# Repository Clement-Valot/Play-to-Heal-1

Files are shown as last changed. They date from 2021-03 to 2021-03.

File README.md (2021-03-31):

# Play-to-Heal

## Résumé

En France, d’après l’INSEE, 3,5 millions de personnes sont en situation de handicap physique. Cela ne concerne que 5% des Français et bien que tous différents, la majorité des handicaps ont un point commun : les exercices de rééducation musculaire.  

L’objectif de ces exercices est de recouvrer partiellement, ou totalement, ses capacités physiques ou encore de simplement les préserver. En faisant travailler ses muscles au travers de la répétition de mouvements particuliers, le patient se réhabitue petit à petit à se mouvoir. Cependant, cela comporte un aspect répétitif et ennuyeux, en particulier pour les enfants, mais c’est nécessaire au maintien ou à l’amélioration des fonctions motrices des patients.  

Ainsi, notre objectif avec Play To Heal est de rendre ces exercices plus ludiques pour les personnes ayant des difficultés motrices. Pour y parvenir nous avons utilisé la gamification, ou ludification, qui est l’utilisation des mécanismes du jeu dans des domaines n’ayant à priori aucun rapport afin de rendre l’expérience utilisateur plus ludique et agréable.  

Notre solution utilise la manette adaptative Xbox, sorti en fin d’année 2018, couplée à un périphérique externe développé par nos soins. Il suffit de placer les électrodes sur un ou plusieurs muscles et les contractions du joueur sont directement utilisées pour agir dans le jeu vidéo. Bien entendu, il est possible de jouer à tous les jeux disponibles sur Xbox, même s’il est conseillé d’en choisir un nécessitant peu de touches si le patient est amené à jouer seul. 

Pour conclure, nous vous invitons à parcourir tous les documents disponibles pour plus d’informations sur le projet si vous n’êtes pas encore convaincu ! 

Pour voir notre vidéo de présentation, c'est ici : https://www.youtube.com/watch?v=-XGQ_6M441o (version sous-titrée en anglais : https://www.youtube.com/watch?v=T63vXXvgbwU )

Pour voir notre vidéo de démo, c'est par là : https://www.youtube.com/watch?v=D4KDB941Q0I 

## Sommaire

#### 3D modeling

Vous trouverez dans ce dossier les modélisations des différentes pièces du boîtier Mono-muscle et Multi-muscle. Pour les deux versions du boîtier, 2 dossiers sont fournis: l'un contenant les pièces au format SolidWorks (.SLDASM) et l'autre au format .STL pour impression en 3D.

#### Codes and libraries

Les 2 sous dossiers (code multi muscles SIG et code multi muscles RAW) contiennent chacun le logo affiché sur l'écran OLED lors de l'allumage du boîtier, nommé "logo.h", et le code Arduino (C++) correspondant.

#### Documentation

Ce dossier est dédié pour toutes informations complémentaires au boîtier Play to Heal concernant: les différents composants électroniques, le filtrage numérique, l'analyse de coûts, etc... 
Tous sont accessibles au format PDF.

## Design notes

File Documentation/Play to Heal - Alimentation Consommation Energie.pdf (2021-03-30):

# Alimentation du dispositif et consommation d’énergie

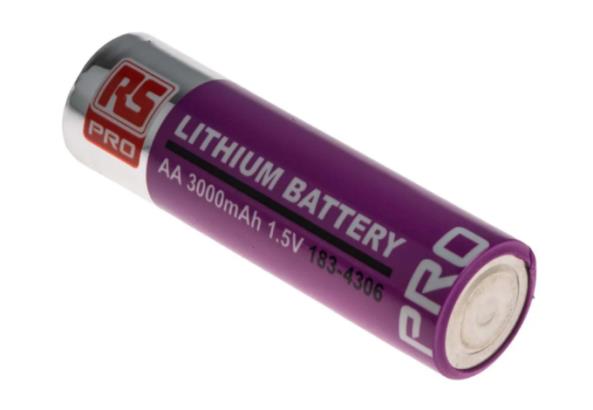
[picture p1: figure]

## Table des matières

## Etat de l’art

L’ESP 32, l’élément central de notre dispositif fonctionne avec une tension comprise entre 2.5 et 3.6 volts. Il faut donc trouver une source d’énergie qui puisse apporter une telle tension. Plusieurs solutions s’offrent à nous :

1. On pourrait brancher le montage directement à la manette Xbox adaptative mais celle-ci offre une tension de 5V qui est au-dessus du seuil maximum de notre microcontrôleur. Il faudrait donc réaliser un montage électrique pour réduire cette tension, ce qui n’est pas optimal.
2. Au contraire, des piles NiMH ou standards n’apportent pas assez de courant pour que l’ESP32 puisse fonctionner correctement. Les piles fournissent environ 1,2V (soit 2.4V avec 2 piles). Or la tension minimale de l’ESP 32 est d’environ 2.55V.
3. Utiliser un banc d’alimentation est également une mauvaise idée car ce type de batterie utilise en interne une batterie au lithium de 3.7V puis transforme la tension afin de délivrer 5V. Il faudra donc ramener de nouveau la tension à 3.6V à l’instar du procédé avec la manette. Les transformations successives sont énergivores et sont à éviter. Enfin ce type de batterie peut parfois s’éteindre car il peut arriver qu’elle pense qu’aucune charge n’est connectée tant l’ESP32 consomme peu de courant.
4. Les batteries LiFePO4 modernes fonctionnent également très bien, mais fournissent environ 70 % d’énergie en moins qu’une batterie au lithium de la même taille. Les batteries LiFePO4 sont bien adaptées à un fonctionnement à court terme, c’est-à-dire des semaines et des mois. Il est également important de noter qu’un chargeur 3V spécial adapté aux batteries LiFePO4 est nécessaire.

Après l’étude de toutes ces possibilités, il s’est avéré que la solution la plus optimale était d’utiliser des piles au lithium. En effet, ce type de batterie délivre une tension constante dans le temps jusqu’à sa fin de vie. Nous avons choisi celles délivrant 1.5V car en les mettant en parallèles nous doublons la tension, ce qui correspond bien aux contraintes de l’ESP32.

## Rôle dans le projet

L’utilisation de ces piles offre une alimentation simple et efficace à notre dispositif. Nous n’avons pas besoin de le brancher sur secteur, ce qui permet d’éviter de s’encombrer avec des fils supplémentaires pour utiliser l’appareil. De plus la longue durée de vie des piles au lithium assure une grande autonomie à notre projet. Nos deux piles de 1,5V vont nous fournir une tension optimale pour alimenter l’ESP32 et l’écran OLED. De plus, leur positionnement dans le boitier permettra à l’utilisateur de les changer facilement lorsqu‘elles cesseront de fonctionner.

## Consommation énergétique

Afin de se rendre compte de la fréquence à laquelle il faudra changer les piles, nous allons dans un premier temps étudier chaque composant demandeur d’énergie puis la source d’énergie et enfin nous associerons le tout.

Ce n’est pas précisé dans les figures qui vont suivre mais la consommation écrite représente toujours la consommation pour une heure de fonctionnement.

### Explication

Comme expliqué dans le choix de la source d’énergie, les piles au lithium sont très fiables et sont la source d’énergie la plus optimisée. En effet, elles maintiennent une tension de 3V assez constante puis à moins de 2,7 volts plus de 90 % de leur capacité est utilisée et enfin à 2,55V elles sont pratiquement vides, or pour fonctionner l’ESP32 à besoin d’au moins 2,55V.

Concernant l’autonomie du système, on peut voir que les piles ont une capacité de 2900mAh. A noter que le fait de les mettre en parallèle n’augmente que la tension et non le courant, ce qui explique pourquoi nous travaillons avec 2900mAh malgré le fait que nous utilisons deux piles.

Pour étudier combien de temps notre système peut fonctionner sans changer les piles, on additionne la consommation de tous les composants pour une heure :

- 40mA (ESP32)
- 9mA (Myoware)
- 40mA (OLED)
Ce qui nous donne 89mAh. Cependant l’écran OLED ne sert qu’à l’initialisation, soit maximum deux minutes sur l’heure de fonctionnement, ainsi il peut être négligé.

Nous ne consommons finalement que 49mAh. De ce fait, notre système pourrait fonctionne plus d’une cinquantaine d’heures (2900/49) avant de changer les piles.

### Consommation par composant

ESP32

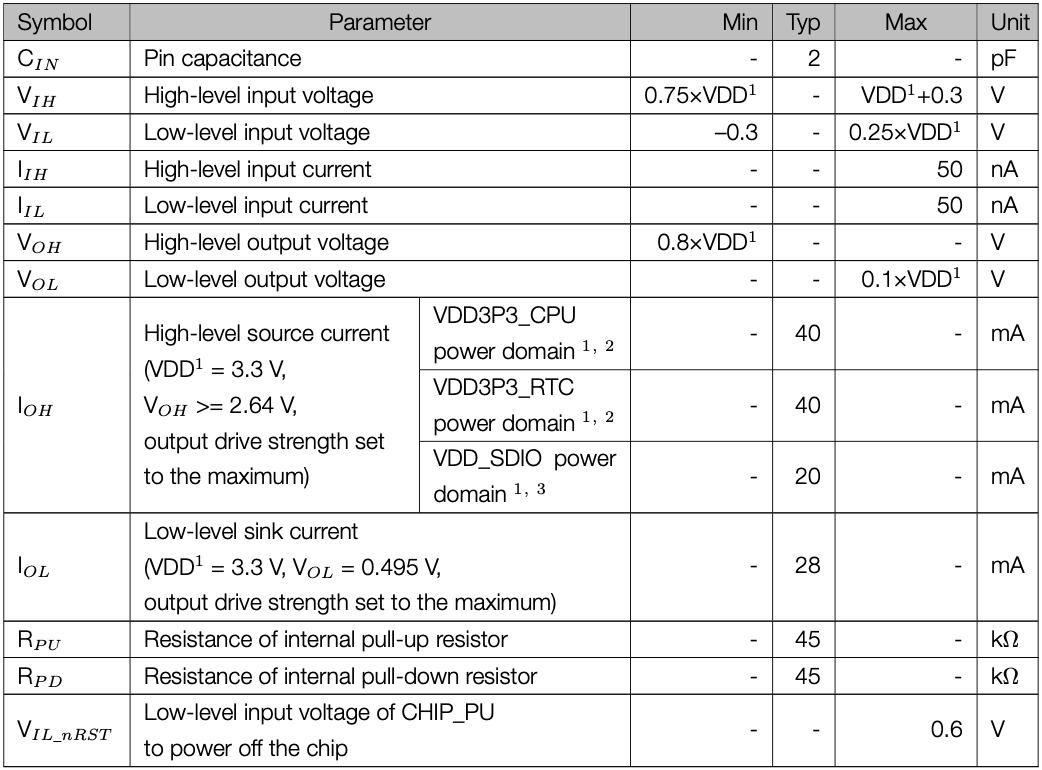
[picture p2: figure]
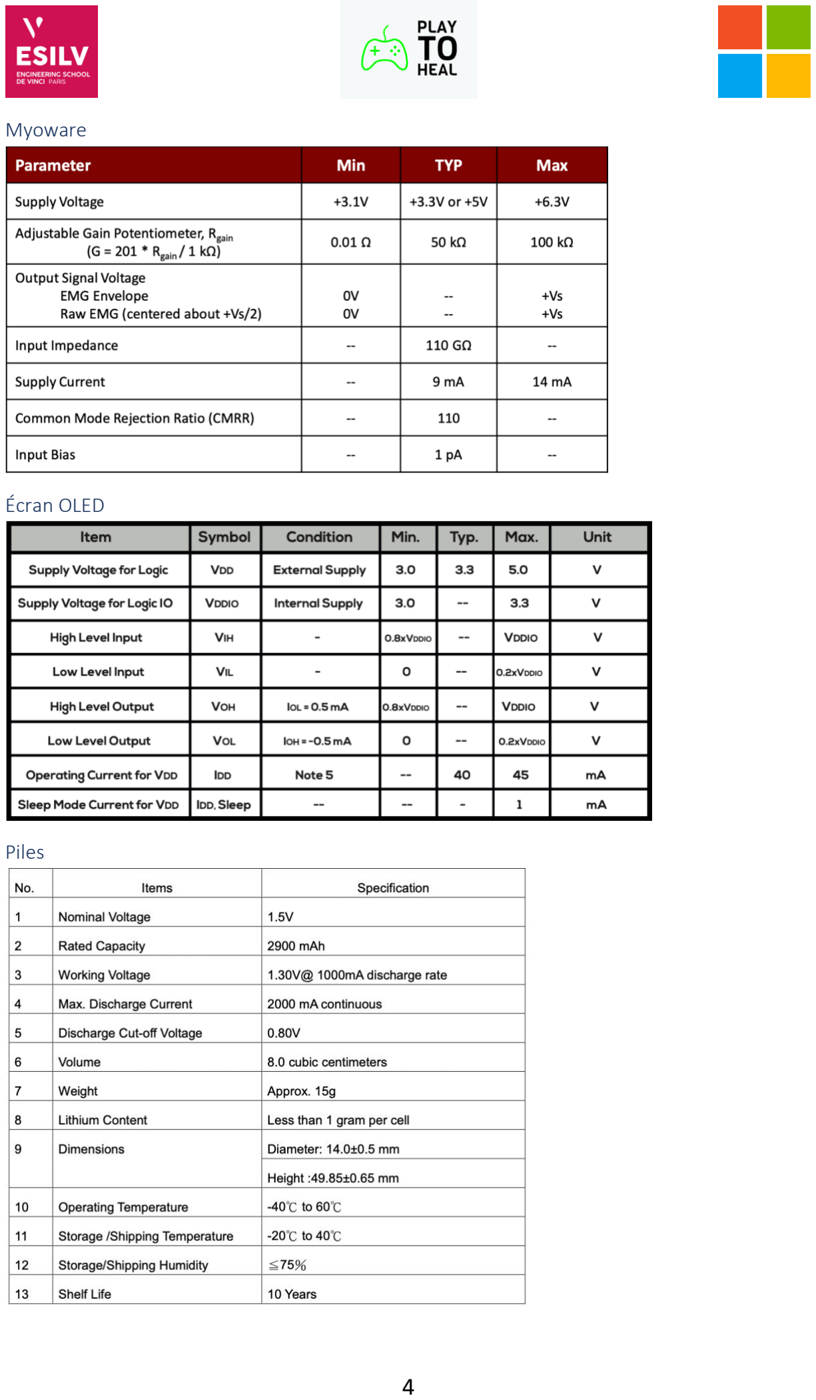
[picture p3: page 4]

Myoware

Écran OLED

Piles

## Bibliographie

https://fr.rs-online.com/web/p/piles-aa/1834306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 (https://fr.rs-online.com/web/p/piles-aa/1834306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)

ESP32 : https://www.espressif.com/sites/default/files/documentation/esp32_datasheet_en.pdf

Myoware : https://cdn.sparkfun.com/assets/a/3/a/f/a/AT-04-001.pdf

OLED: | https://cdn.shopify.com/s/files/1/1509/1638/files/1_3_Zoll_Display_Datenblatt_AZ-
Delivery_Vertriebs_GmbH_rev.pdf?v=1606164520 (https://cdn.shopify.com/s/files/1/1509/1638/files/1_3_Zoll_Display_Datenblatt_AZ-Delivery_Vertriebs_GmbH_rev.pdf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)

Piles : https://docs.rs-online.com/0394/0900766b81707a84.pdf

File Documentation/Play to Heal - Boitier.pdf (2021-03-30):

# Boitier

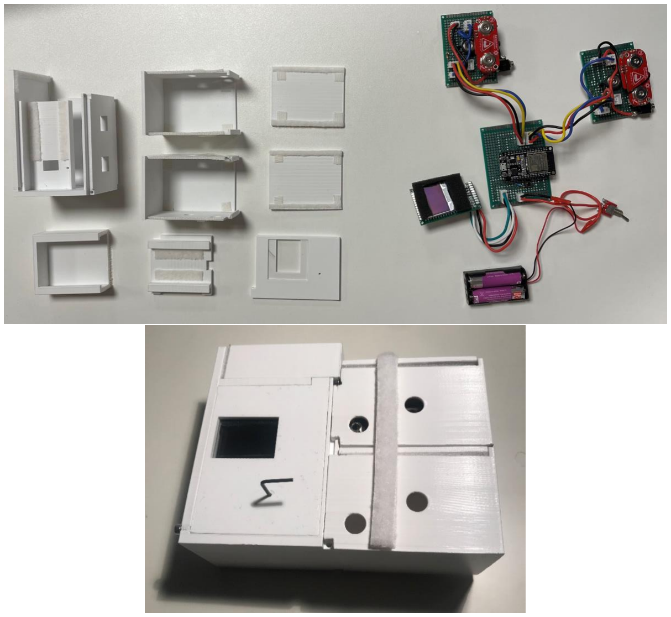
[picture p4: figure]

## Table des matières

1
2
1
2

## Introduction

Pour commencer, il faut savoir que nous avions pour objectif de rendre un produit industrialisable. De ce fait, rendre le projet sous forme de PCB connectés entre eux par des fils n’était pas suffisant. C’est ainsi que nous est venue l’idée d’un boitier permettant de délivrer notre projet sous une forme concrète.

En effet, le boitier s’est révélé comme étant la solution idéale pour rendre un projet fini à la fin de l’année. Il a les avantages d’être :

- esthétique car il cache les composants électroniques,
- sécurisé car les composants électroniques ont moins de chances de s’abimer
- pratique car il est facile à monter même pour quelqu’un qui ne s’y connaît pas,
- transportable car l’optimisation de l’espace pour les composants a été optimisé au maximum et que le boitier tient dans une main.
- professionnel car il représente l’aspect fini et abouti de ce projet.

Cette idée était d’autant plus réalisable que nous étions 9 dans l’équipe et avions donc plus de moyens humains pour dédier plusieurs personnes du groupe à sa conception, en l’occurrence deux. Les imprimantes du pôle mises à disposition au FabLab nous ont également été d’une grande aide.

Aujourd’hui, nous sommes très fiers du modèle multi muscles que nous avons produit parce qu’il représente réellement toute l’implication et l’effort mis dans ce projet par toute l’équipe. Dans ce document, nous allons expliquer la démarche que nous avons suivi de la réflexion à la construction en passant par la conception.

## Par où commencer ?

Notre toute première initiative de construction de boitier était de récupérer des planches de bois de 3mm au FabLab et de limer leurs côtés pour pouvoir les imbriquer entre elles.

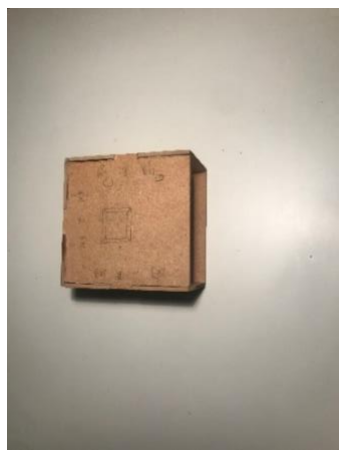
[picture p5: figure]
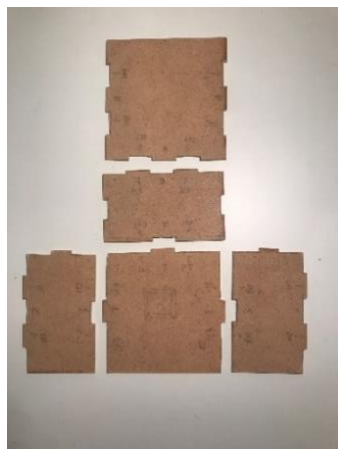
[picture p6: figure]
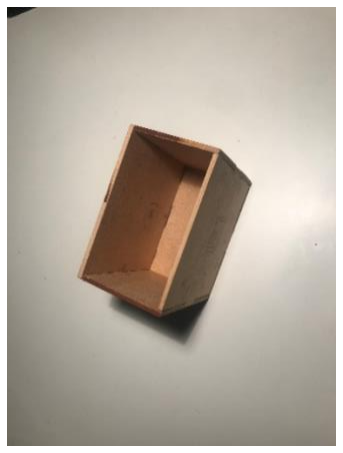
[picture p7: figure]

Le résultat n’est pas fameux mais le but était de nous faire prendre conscience que pour construire notre boitier, il fallait commencer par se poser les bonnes questions :

- Quelles vont être les dimensions du boitier ?
- Que devons-nous pouvoir mettre à l’intérieur ? Comment fixer les composants à l’intérieur du boitier pour éviter qu’ils soient volatiles et qu’ils s’abîment à la moindre secousse du boitier ?

- Quels composants doivent être accessibles par l’utilisateur et lesquels doivent être cachés ?
- Une boîte ne pouvant pas être modélisée avec une imprimante 3D de notre FabLab, combien de pièces différentes devons-nous concevoir ?
- Le boitier doit-il pouvoir être démontable facilement ?
- En quel matériau le construire (bois, imprimante 3D, plastique, métal) ?
- Comment placer l’OLED dans le boitier tout en le rendant visible depuis l’extérieur ?
- Comment fixer les différentes pièces entre elles ? Imbrication parfaite ? Vis ? Scratch ? Scotch ? Colle ?
- Comment rendre des éléments accessibles par l’extérieur sans ouvrir le boitier ? (pour l’interrupteur, l’embout du myoware pour y brancher les électrodes, la prise jack femelle, ainsi que le bouton connecté à l’ESP32)

Nous sommes rapidement arrivés à la conclusion qu’il fallait que l’on construise notre boitier à l’aide d’une imprimante 3D. Et pour cela, nous avions besoin d’un logiciel de modélisation 3D et nous avons donc récupéré des licences SolidWorks fournies par l’école.

A partir de là, le schéma était plus clair dans nos têtes :

1. Il fallait commencer par modéliser les pièces électroniques composant notre produit (myoware, esp32, jack femelle…) afin de voir en les rapprochant au maximum quels pourraient être les dimensions optimales du boitier.
2. Ensuite, il fallait esquisser un premier modèle de boitier permettant d’imbriquer chaque composants à l’intérieur en prenant soin de ne pas laisser trop de leste. De plus, il fallait bien séparer le nombre de pièces afin de rendre le montage le plus simple possible.
3. Enfin il fallait imprimer pour voir concrètement ce à quoi nous n’avions pas pensé et ce qu’il fallait changer.

## Modélisation des pièces électroniques

Il n’y a pas grand-chose à dire sur la modélisation de ces pièces si ce n’est qu’elles restaient assez précises et difficiles à modéliser. Mais leur importance était grande car c’est elles qui nous ont permis de voir si le boitier imprimé allait bien faire rentrer les vrais composants. Malheureusement, ces pièces n’ont pas résolu tous nos maux notamment ceux liés à l’imbrication des pièces entre elles, les défauts de modélisation dus au support des imprimantes ou encore les trous/espaces nécessaires aux fils et câbles.

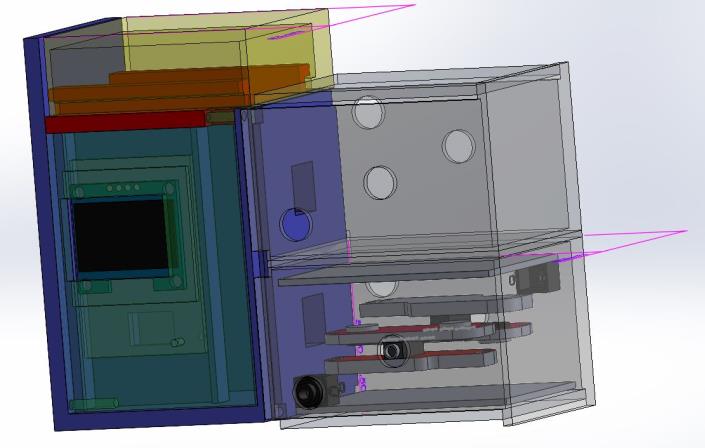
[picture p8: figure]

Evidemment, ces pièces-là n’ont pas été imprimées, elles ont seulement servi de repère pour modéliser le boitier sur SolidWorks.

## Modélisation des pièces du boitier

Il est impossible de construire une boite telle quelle avec une imprimante 3D. Pour ce faire, il faut créer différentes pièces que l’on fixe ensuite entre elles pour former la boîte. Dans notre cas nous avons imaginé notre boitier en 4 pièces :

1. La pièce principale qui va être le squelette de notre boitier et contenir la plupart des composants électroniques. Elle doit être faite de telle sorte qu’elle puisse laisse sortir le levier de l’interrupteur mais aussi des prises jack par des petitstrous, et que les composants puissent être placés facilement à l’intérieur de celle-ci.

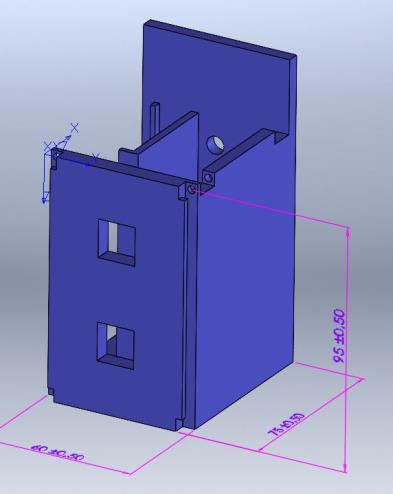
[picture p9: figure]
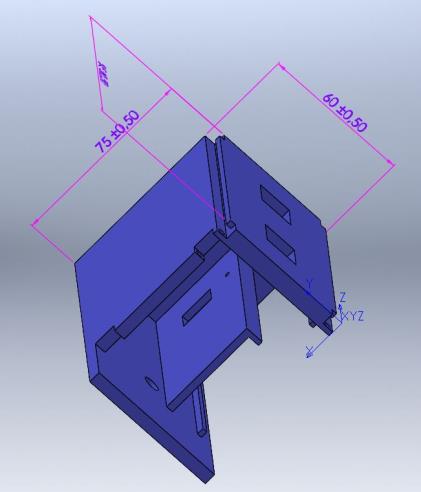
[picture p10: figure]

2. La face OLED qui va recouvrir une face ouverte de la pièce principale en laissant une ouverture rectangulaire pour voir l’OLED (sur laquelle on placerait du plexiglas) et un trou pour y placer le bouton atteignant l’ESP32.

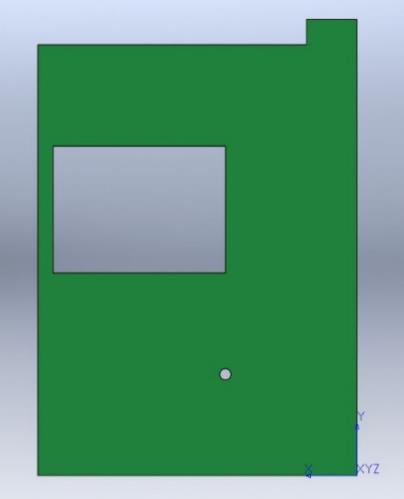
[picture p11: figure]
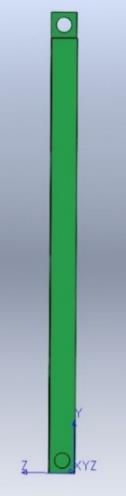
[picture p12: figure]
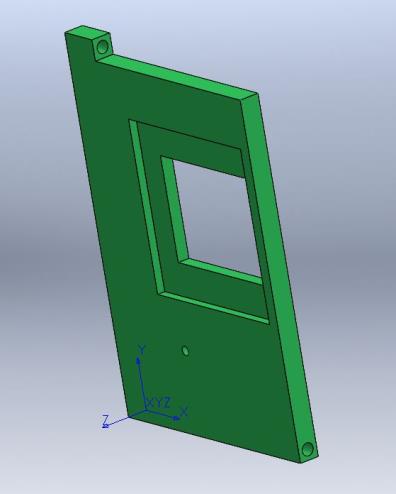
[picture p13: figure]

3. Le supporte-pile qui recouvre la dernière face ouverte supérieure de la pièce principale et qui comme son nom l’indique sert à y placer le porte-pile. Il était nécessaire pour nous de rendre les piles accessibles facilement tout en cachant les fils et cartes électroniques, comme dans tout composant, d’où la mise à l’écart du porte pile.

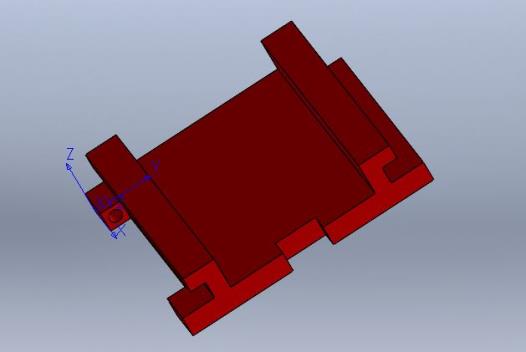
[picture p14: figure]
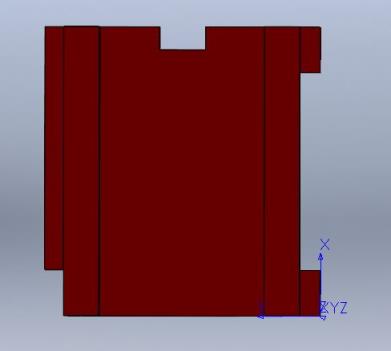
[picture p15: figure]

4. Le capuchon pouvant glisser et s’imbriquer sur le supporte-pile et permettant de cacher le porte-pile.

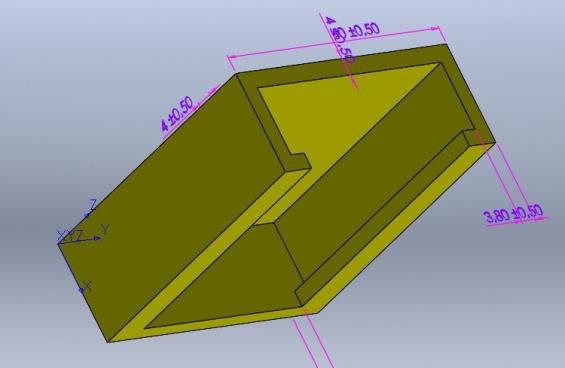
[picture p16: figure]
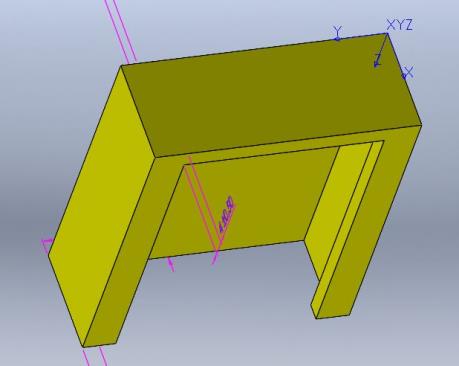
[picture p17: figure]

Plus tard pour le modèle multimuscles, on rajoutera une 5ème pièce : l’extension.

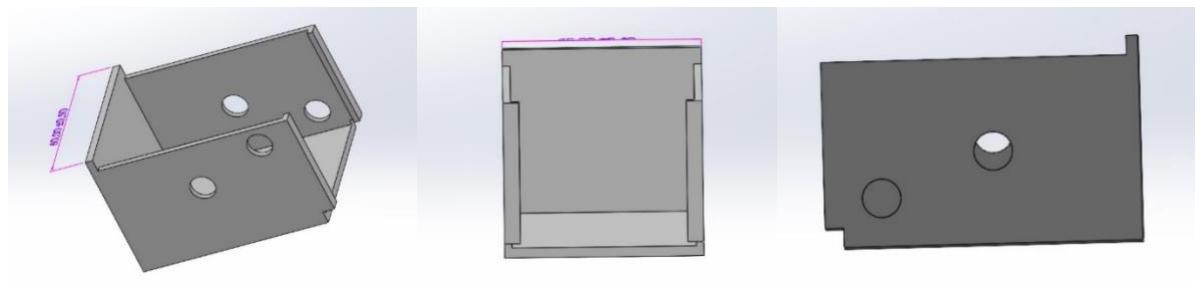
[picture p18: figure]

A ne pas s’y méprendre, il était impossible de réussir notre modélisation du premier coup. Au total, ce n’est pas moins de 4 impressions 3D qu’il nous a fallu pour arriver à notre résultat.
1

## er modèle monomuscle

Notre première modélisation et impression nous a fait rendre compte que la construction de ce boitier n’allait pas être tâche facile. Les défauts sur cette impression étaient nombreux :

- Les dimensions ayant été calculées au millimètre près, et l’imprimante 3D ayant une précision à 0.3mm près ont provoqué des soucis de collision et d’imbrication notamment entre le supporte-pile et le capuchon, mais aussi entre la pièce principale et la face OLED.
- La face OLED portait mal son nom puisqu’elle ne disposait pas du trou permettant de voir l’OLED à l’intérieur du boitier
- Le petit carré présent sur le capuchon et prévu pour le placement d’un scratch était tout sauf une bonne idée
- Le remplissage à l’intérieur de la pièce principale prenait beaucoup trop de temps et était inutile

- L’espace laissé pour le myoware et son PCB était trop court ce qui provoquait de la friction entre les parois et le myoware
- Les trous réservés à l’interrupteur, à la prise jack femelle et au myoware n’étaient pas du tout bien placés. Le trou pour le bouton de l’ESP32 n’était pas du tout bien placé non plus.
- Le support pour l’OLED dans la pièce principale manquait d’un trou pour laisser passer les files reliés à l’OLED
- Les pièces ont été imprimées d’une couleur différente ce qui donnait un rendu assez laid.

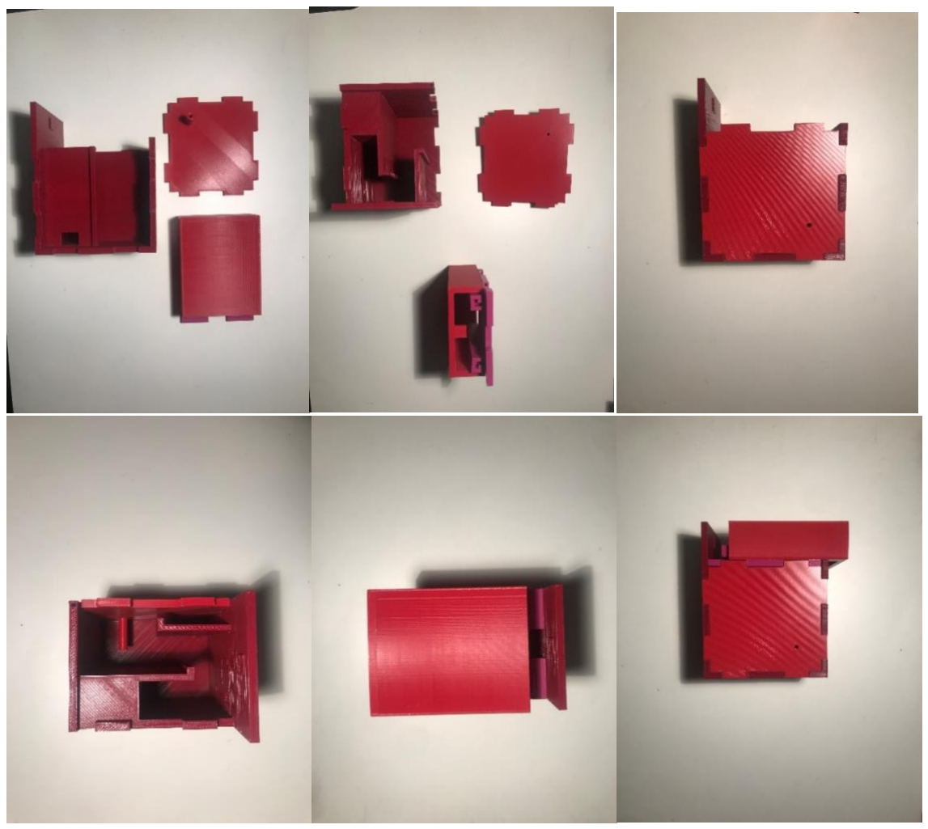
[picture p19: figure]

A partir de ces observations, nous avons pu remodéliser chaque pièce de ce boitier.

2

## ème modèle monomuscle

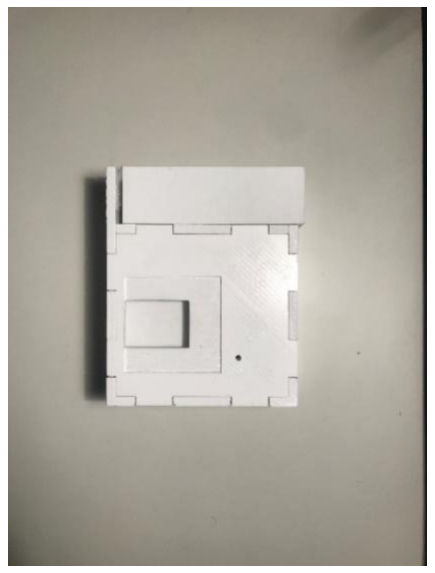
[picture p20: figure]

Ce modèle est bien plus abouti que le précédent, il règle tous les soucis précédemment cités et est fonctionnel pour jouer avec un muscle. Tous les composants électroniques rentrent parfaitement, les trous sont présents et au bon endroit, imbrication sans problème de toutes les pièces entre elles. Cette fois-ci, nous avons fait attention à bien imprimer toutes les pièces de la même couleur ce qui fait que le résultat est beaucoup plus esthétique.

Il faut également noter que les petits trous cylindriques de 3mm de diamètre faits dans le but d’y passer des tiges pour garantir la stabilité des pièces entre elles, se sont en fait avérés parfaits pour y placer des vis qui tiennent de manière beaucoup plus solides (coup de chance).

Nous étions satisfaits de ce modèle car il était fonctionnel mais il y avait encore des éléments à améliorer :

- Ce modèle ne pouvait accepter qu’un seul muscle à la fois ce qui voulait dire que si un utilisateur voulait jouer avec plusieurs muscles sur un jeu, il lui fallait acheter plusieurs fois ce boitier.
- Le boitier restait volumineux et beaucoup d’espace à l’intérieur de celui-ci était inutilisé
- Certaines pièces étaient mal designées comme la face OLED qui avait un long cylindre de plusieurs cm afin de faire passer la tige/bouton et éviter que ce dernier ne bouge de trop ; ou encore les côtés crantés qui ne sont pas du tout optimums.
- Les marges créées par l’utilisation du scratch n’étaient pas prises en compte et surtout les possibilités offertes par le scratch n’étaient pas assez exploitées.

C’est à partir de là que nous avons commencé à réfléchir à un boitier permettant de connecter plusieurs muscles (myowares) à l’ESP32.

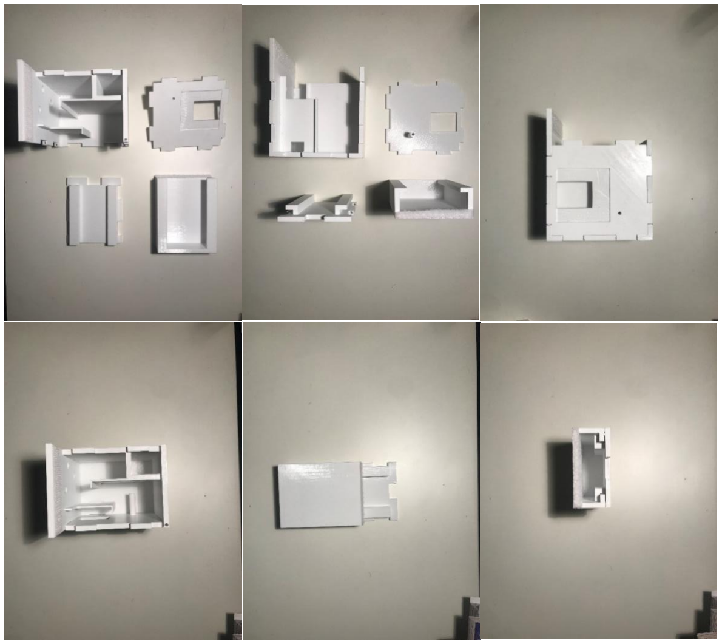
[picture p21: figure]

1

## er modèle multimuscles

On compte 3 PCB pour un modèle monomuscle : le PCB OLED, le PCB ESP32 et le PCB myoware. Si on veut ajouter un muscle, il suffit simplement de rajouter un PCB myoware et de le connecter au PCB ESP32, le PCB OLED reste quant à lui inchangé. Avec ces informations, nous en sommes donc venus à la conclusion que notre boitier multimuscles serait composé d’une partie principale contenant les PCB ESP32 et OLED, puis de parties annexes dites « extensions » contenant les PCB myoware.

Ces extensions seraient clipsables au boitier principal tels les joycons d’une Nintendo switch. Au total, ce n’est pas moins de 4 extensions contenant 2 PCB myoware chacune (pour un maximum de 8 muscles !!) qui pourraient être accrochées au boitier. Pour les rendre clipsables, il nous a fallu épaissir un bord de la pièce principale afin de pouvoir y intégrer des rails sur lesquelles glisseront les extensions. Sur notre modèle, nous n’avons épaissi que le bord droit (en regardant l’OLED) pour y mettre deux extensions (4 muscles maximum), mais ceci peut aussi être fait sur le bord gauche.

Ainsi, en enlevant le PCB myoware de la partie principale du boitier, on gagne énormément de place et on peut ainsi grandement diminuer la largeur de la pièce principale pour la rendre aussi large que la largeur du PCB ESP32. La hauteur du boitier est aussi presque similaire à ce PCB.

Malheureusement, quelques soucis sont encore apparus après l’impression des pièces de ce nouveau boitier :

- Le supporte-pile et le capuchon ne s’imbriquait pas correctement due à des soucis d’impression avec le support non pris en compte (le FabLab n’avait pas imprimé les pièces dans le sens que je voulais ce qui avait créé des supports à des endroits indésirables)
- La face OLED avait un taux de remplissage faible ce qui la rendait fragile et peu esthétique. De plus, nous nous sommes rendu compte qu’il serait préférable de ne pas mettre la face où on colle le plexiglas vers l’extérieur mais plutôt vers l’intérieur.
- L’extension n’avait pas du tout été bien pensée. D’une part, ses dimensions en hauteur et largeur ne permettaient pas de placer deux myowares en son sein. D’autre part, les trous destinés à la prise jack femelle et la prise du myoware n’étaient pas bien placés pour l’un des myowares. Aussi, les rails de l’extensions possédaient du support dû à l’impression donc l’extension ne glissait pas bien du tout sur les rails de la pièce principale. Mais surtout, nous avons pensé cette extension comme une boite alors qu’il aurait fallu rendre son toit amovible. En effet, même si nous avions laissé un trou sur le toit des extensions pour laisser passer les fils venant de l’ESP32 pour les connecter aux myowares, il restait impossible de brancher les fils sur les nappes des myowares compte tenu du si petit trou.
- En diminuant la largeur du boitier, le bouton du PCB de l’ESP32 s’est retrouvé en dessous du PCB OLED et donc inatteignable par la tige comme sur le précédent boitier. Il faut donc couper une partie du PCB OLED et faire un trou sur la face le supportant.

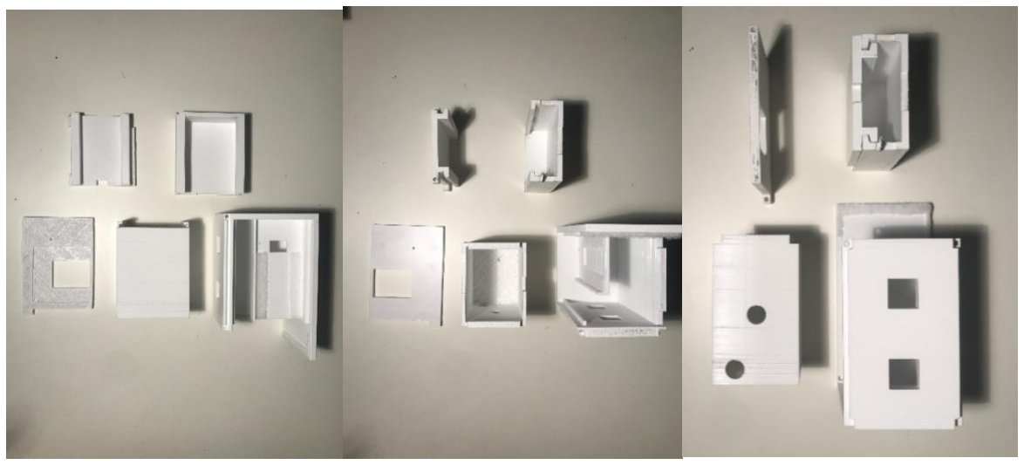
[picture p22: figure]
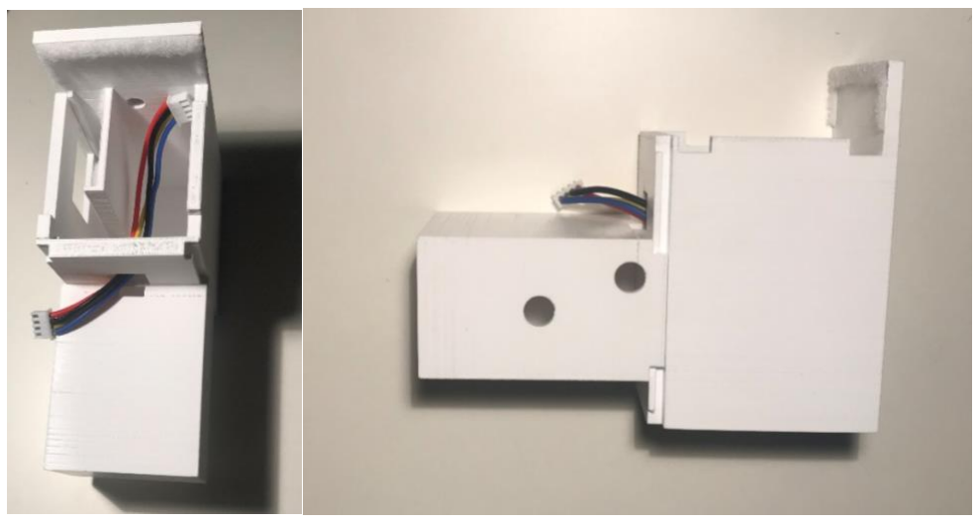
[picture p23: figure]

2

## ème modèle multimuscles

Dernière modélisation, derniers ajustements faits, premier sans fautes :

- Toutes les pièces s’imbriquent parfaitement entre elles
- Les extensions glissent bien sur les rails
- Les trous sont aux bons endroits pour les jacks, l’interrupteur, les vis et le bouton
- Les marges en fonction des scratchs ont été prises en compte
- Tous les composants sont bien fixés à l’intérieur du boitier, aucune volatilité

Pour palier au problème des extensions, nous avons simplement ôté la partie supérieure ce qui nous permet de faire rentrer plus facilement les myowares à l’intérieur et également de les brancher plus aisément avec l’ESP32. Pour refermer ces extensions, on a une face supplémentaire que l’on accroche à l’aide de scratch ce qui donne également une sorte de marge supplémentaire au cas où les deux myowares ne s’imbriquent pas parfaitement.

Le scratch est un composant très important de notre boitier. On s’en sert à la fois pour fixer les PCB au sein du boitier et ainsi éviter qu’ils flottent à l’intérieur, mais il permet aussi de fermer le capuchon de manière plus solide ou de fixer les extensions entre elles pour éviter que leur parties supérieures ne se décrochent à cause de pression trop importante.

Afin de stabiliser l’interrupteur dans son trou, on a dû trouver des boulons de 7mm de diamètre.

Les vis se sont révélées extrêmement utiles afin de fixer les pièces du boitier entre elles.

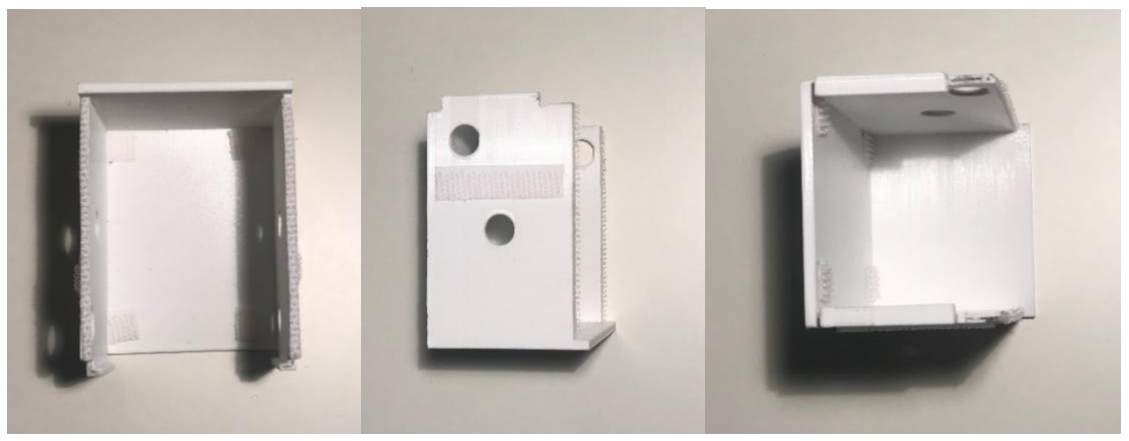
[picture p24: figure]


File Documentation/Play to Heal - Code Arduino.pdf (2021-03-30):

# Explication code

## Table des matières

## Lien du gitHub: https://github.com/RemiEC/Play-to-Heal

## Introduction

Dans notre boitier, ce sont les myowares qui sont chargés de capter les signaux émis par les muscles. Mais il ne suffit pas de connecter ces myowares à la manette adaptative Xbox afin de déclencher les actions des boutons. En effet, les signaux envoyés par les myowares étant analogiques, il nous faut un intermédiaire qui puisse les convertir en signaux digitaux et plus précisément binaires : « 1 » si le muscle est contracté, « 0 » sinon. Et cet intermédiaire, c’est l’ESP32 avec son processeur qui va nous permettre de traiter les données reçues du myoware.

Dans l’ordre, on a donc les myowares qui enregistrent les signaux musculaires, l’ESP32 qui reçoit ces signaux, les traite et envoie un signal digital binaire à la manette adaptative qui active ou non les boutons pour le jeu. Mais la question qui se pose est : comment différencier un signal venant d’un muscle contracté et celui d’un muscle au repos ? La réponse est qu’il faut mettre en place des seuils, et c’est là toute l’utilité du code Arduino que nous avons implémenté.

Bien évidemment, le code Arduino ne se résume pas à mettre en place un seuil en brut établi de manière empirique, puis de comparer si les signaux reçus sont au-dessus ou en-dessous pour déclencher ou non les boutons. Et cela pour 2 raisons :

- d’une part, tous les muscles du corps n’envoient pas les mêmes signaux et l’intensité du signal d’un état contracté pour l’un peut correspondre à un état au repos pour l’autre ;
- d’autre part, le même muscle de deux utilisateurs différents peut envoyer des signaux complètement différents.

Il nous faut donc établir ces seuils de manière dynamique pour chaque utilisateur et pour chaque muscle de ces derniers.

Pour les connaisseurs de l’IDE Arduino, le code se sépare en 3 parties :

1. Une partie de déclaration de constantes (pins notamment), variables globales et bibliothèques à utiliser.

2. La partie setup qui comme son nom l’indique met en place l’environnement de travail du processeur (compter le nombre de muscles à connecter, établir leur seuil).
3. La partie loop qui itère à l’infini pour détecter si les signaux envoyés correspondent bien à des contractions.

Il est à noter que sur le github, plusieurs versions du code sont à disposition:

- Tout d’abord, il y a les versions monomuscles et multimuscles. Dans la version multimuscles, on va donner la possibilité à l’utilisateur de connecter plusieurs muscles au boitier là où la version monomuscle ne permet d’en connecter qu’un seul. Dans la suite du rapport, c’est la version multimuscles qui est présentée.
- Ensuite, il y a le code SIG et le code RAW. La différence se fait au niveau du traitement du signal reçu dans l’ESP32. Le code SIG récupère les signaux captés par le myoware et réalise une simple moyenne sur ces valeurs pour déterminer le seuil de contraction d’un muscle (processus détaillé ci-dessous). Le code RAW va récupérer le signal du myoware en amplitude et non en fréquence. Ces données sont plus précises mais plus volatiles d’où la nécessité de devoir filtrer les signaux reçus. Et pour ce faire on utilise des librairies bien spécifiques détaillées ci-dessous. Comme les codes SIG et RAW sont quasi-similaires, nous n’allons pas faire deux parties distinctes mais simplement mettre du texte en rouge pour indiquer les différences entre les deux codes.

## Librairies, constantes, variables globales

Les librairies sont la première chose à mentionner dans un code. Elles sont appelées avec « #include » :

1. #include <Wire.h> : permet une communication I2C entre le Myoware et l’ESP32. Il permet
aussi | la | transmission | d’information | sur | les | pins | du | OLED
https://www.arduino.cc/en/reference/wire
2. #include <U8g2lib.h> : cette bibliothèque permet d’écrire des informations sur l’OLED. Elle n’est pas indispensable au traitement des signaux mais elle reste très importante pour afficher
les | résultats | et | permettre | une | interaction | avec | l’utilisateur
https://www.arduino.cc/reference/en/libraries/u8g2/
3. #include <Filters.h> et #include <Filters/Butterworth.hpp> : ces deux bibliothèques permettent d’appeler des méthodes de filtre de butterworth pour filtrer les données reçues du myoware.
4. #include "logo.h" : n’est pas une bibliothèque et est très accessoire, elle permet seulement d’afficher le logo du pôle léonard de vinci lors du lancement du programme

Les constantes sont des éléments très importants qui correspondent aux pins des capteurs, des boutons, des transistors, et aux valeurs maximum ou minimum (nombre de muscles max) à définir :

1. Pin_Capteur[] : tableau comprenant les pins de l’ESP32 qui reçoivent les signaux des myowares. Si 3 muscles peuvent être connectés à l’ESP32, alors 3 entiers devraient se trouver dans ce tableau. Cela n’est pas grave si ce tableau possède 3 entiers et que un seul muscle est connecté, il y aura juste des valeurs inutilisées.
2. Pin_Transistor[] : tableau contenant les valeurs des pins qui renvoient le signal digital à la manette adaptative. Il doit y avoir autant de valeurs dans ce tableau que dans le tableau précédent.
3. Max_muscles : nombre maximum de muscles pouvant être connectés au boitier (contraint par le PCB de l’ESP32 et le nombre de myowares à disposition)

4. buttonPin, buttonHigh : pins du bouton
5. const int nEchantillons = 20 : nombre de valeurs que l’on met dans le tableau d’échantillon pour calculer une moyenne glissante des valeurs captées par le myoware.
6. auto filter1 = butter<4>(f_n) : premier filtre passe-haut ; f_n correspond à la fréquence de coupure
7. auto filter2 = butter<4>(f_n2) : deuxième filtre passe-haut ; f_n2 correspond à la fréquence de coupure.
Veuillez noter que plus tard dans le code, on effectue la soustraction du premier filtre par ce deuxième filtre pour faire un filtre passe-bande.

Les variables globales sont des objets accessibles et modifiables partout dans le code que ce soit le setup, le loop ou encore les fonctions

1. Theshold[Max_muscles] : tableau contenant les seuils pour chaque muscle
2. Array_values[128] : tableau accessoire qui sert à l’affichage des courbes sur l’OLED du signal renvoyé par les myowares. 128 correspond au nombre de pixels sur la largeur de l’écran OLED.
3. float echantillon[nEchantillons] : tableau d’échantillon avec lequel on calcule la moyenne glissante.

## Setup

On commence par initialiser l’environnement avec la librairie de l’OLED (police), puis le Serial et enfin on déclare les pin modes pour le bouton.

Partout dans le code on retrouve des appels à la fonction DisplayOLED. Cette fonction prend en paramètre un string et un int et affiche sur l’OLED le string à la position indiquée par l’entier (0 : en haut, 1 : milieu, 2 : en bas). Attention à ne pas rentrer de string trop long, auquel cas le texte sortira de l’écran (pas de retour à la ligne automatique). Cette fonction sert surtout à guider l’utilisateur dans les étapes à suivre, comme un tutoriel. Au total, sur les 7 fonctions qui composent ce programme, 4 sont destinées à l’affichage OLED et ne sont donc pas indispensables au bon fonctionnement du programme. Elles restent cependant extrêmement importante pour l’UX.

Avant de rentrer dans les calculs de seuils, il nous faut déterminer combien de muscles l’utilisateur veut connecter. La fonction CountMuscles va donc demander à l’utilisateur d’appuyer sur le bouton afin d’incrémenter le nombre de muscle. Si le nombre de muscles dépasse le nombre max de muscles que l’on peut connecter, alors la fonction retourne à 1. Pour valider son choix, l’utilisateur doit rester appuyer pendant deux secondes sur le bouton.

Une fois le nombre de muscles à connecter sélectionné, on rentre dans la boucle qui va calculer les seuils et qui va se répéter autant de fois qu’il y a de muscles à connecter. Pour calculer les seuils, il nous faut deux choses : la moyenne du signal lorsque le muscle est décontracté et la moyenne du signal lorsque le muscle est contracté. De cette manière, on va pouvoir établir une valeur entre moyenne_max et moyenne_min qui sera représentative d’une contraction. Si on prenait moyenne max comme seuil, il se pourrait que l’on rate certaines contractions. Et si on prenait moyenne min comme seuil, le programme pourrait interpréter des contractions là où il n’y en a pas. Par conséquent, une valeur assez éloignée des deux moyennes nous assure une bonne précision avec peu d’erreur pour la détection de contraction. Pour le code RAW, les moyennes min et max sont calculées en prenant la moyenne des racines carrées des moyennes glissantes calculées avec le tableau d’échantillons (qui s’update constamment) . La valeur du seuil est ensuite mise dans le tableau threshold[].

## Loop

Dans la boucle, pour chaque muscle, il nous faut vérifier si le signal capté par le myoware est supérieur ou non au seuil précédemment calculé. Pour se faire, on crée une boucle for qui itère sur chaque muscle et qui appelle la fonction SendSignal.

SendSignal va simplement comparer la valeur lue par le myoware avec le seuil pour ce muscle et mettre la pin transistor de ce muscle à High si il y a contraction (« digitalWrite(pin_Transistor[m], HIGH); ») ou Low sinon. Pour le RAW, on prend la moyenne glissante des dernières valeurs lues par le myoware (sur lesquelles on a appliqué le filtre passe-bande), on prend la racine carrée de cette moyenne et on la compare au seuil. On affiche également sur l’OLED s’il y a contraction ou non afin de voir plus facilement si le programme fonctionne correctement.

## Nota Bene

Il est à noter que le code RAW, bien qu’il fonctionne, reste incomplet et mérite d’être peaufiné afin de traiter des signaux plus propres et plus précis. Celui-ci renvoie un signal en fréquence qui mérite de ce fait d’être traité contrairement au SIG qui renvoie un signal en amplitude. A l’heure actuelle, le code SIG est très efficace et détecte les contractions de manière fiable et sûre. Le perfectionnement du code RAW fait donc partie des axes d’améliorations du projet.

De plus, pour passer de l’analyse SIG au RAW, il suffit simplement de changer la nappe (fil bleu) sur le PCB myoware et de téléverser le bon code dans l’ESP32 (pris sur git).

Pour ce qui est des améliorations à apporter au code, la fonction display OLED pourrait être grandement simplifiée si les tableaux de string étaient bien pris en compte par Arduino (ce qui n’est pas du tout le cas et cela implique énormément de bugs). Certains morceaux de codes peuvent être remplacés par des fonctions existantes pour réduire le nombre de ligne. De même que les délais peuvent être diminués voire supprimés dans certains cas.

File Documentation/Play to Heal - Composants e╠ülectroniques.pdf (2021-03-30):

# Composants électroniques

## Table des matières

## ESP32

### Etat de l’art


Dans ce projet nous avions besoin d’un microprocesseur pour rendre le projet viable et faisable. Lors de nos différents passés et de nos recherches, nous avons trouvé que le microprocesseur proposé par Arduino (ATMEGA328) avait trop peu de RAM et surtout une fréquence d’horloge trop basse. Notre choix c’est donc porté sur un ESP32 qui a une fréquence d’horloge plus élevée et plus de RAM. Dans notre projet, la vitesse de calcul et son traitement sont très important.

La taille des données à récupérer n’est pas très grande donc l’adressage n’est pas un problème. La mémoire flash nous importe peu étant donné que nous n’avons aucune sauvegarde de données après que le dispositif a été éteint.

Pour les entrées et les sorties nous avons besoins d’une entrée analogique (réception donnée des sensors)soit une par muscle, une sortie digitale ou analogique (envoi de données à la manette) et pour finir, une sortie et une entrée pour l’écran OLED.

Pour le prix : nous recherchons un produit réalisable pour le moins chère possible avec un objectif de 30/40€ de ventes, puis un ajout par muscle.

Comparatif ESP VS ATMEGA328 :

ATMEGA328 (Arduino) | ESP32 (board MCU)
Adressage | 8 bits | 32 bits
Fréquence d’horloge | 16 Mhz | 240 Mhz
Mémoire Flash | 32 kB | 4 Mb
Mémoire RAM | 2 kB | 512 kB
E/S Numérique | 14 (6 PWM) | 19
E/S Analogiques | 6 | 15
Taille | 6,9 x 5,3 cm (Arduino Uno) | 48 x 26 x 11,5 mm (NodeMCU)
Prix | 16,25€ HT sur GoTronic | 8€ seul ou 10€ HT sur board

### Avantage de l’ESP32

Ce microcontrôleur permet de gérer des données de grandes tailles (adressage 32 bits) assez rapidement grâce à sa fréquence d’horloge nettement supérieur à celle d’Arduino (plus de 4 fois supérieure minimum). Sa mémoire flash est importante ici mais nous n’en n’aurons pas nécessairement l’utilité. Sa mémoire RAM est intéressante si l’on doit effectuer des filtres complexes, nous aurons peut-être besoin de stocker un certain nombre de variable. L’ESP32 possède ces avantages tout en gardant un rapport qualité / puissance / prix imbattable comparé aux autres microcontrôleurs disponibles sur le marché. Un autre point positif est au niveau de la taille, il est plus petit que la plupart des autres microcontrôleurs dans sa gamme de prix. Il est surtout beaucoup plus petit qu’une carte Arduino notamment.

Enfin, et peut-être le point le plus important, le microcontrôleur est compatible avec l’IDE Arduino. Dans notre projet, le microcontrôleur permet de filtrer le signal des EMG sensors, envoyer des informations à l’écran et envoyé des signaux à la manette adaptative Xbox. C’est le cerveau et la pièce maitresse du projet !

### Configurer l’ESP32 sur l’IDE Arduino


Dans un premier temps il faut télécharger la « bibliothèque » de l’ESP32 comme suit :

- Aller dans fichier puis sélectionner préférences


- Coller l’adresse https://dl.espressif.com/dl/package_esp32_index.json dans la barre « URL de gestionnaire de cartes supplémentaires » puis cliquer sur ok


- Une fois ceci fait, aller dans Outil – Type de carte – Gestionnaire de carte et entrer « ESP32 » dans la barre de recherche


- Cliquer sur « Installer » et attendre quelques instants
- Sélectionner ensuite « DOIVT ESP32 DVKIT V1 » dans la liste des cartes installés pour pouvoir utiliser l’ESP32


- Le langage pour programmer l’ESP32 est le même que celui pour un Arduino Uno. Attention cependant à bien nommer les pins utilisés dans votre code.


Ci-dessus un schéma récapitulant les noms des pins de l’ESP32

### Glossaire

Fréquence d’horloge : vitesse de calcul et transfert des données, caractérise la puissance de traitement ou le débit d’information (nombre d’instructions réalisable en 1 seconde)

Mémoire RAM : sert à stocker des données temporaires (variables par exemple). Si cette mémoire vient à être dépassé, l’application peut crash sans plus d’informations. Ce crash sera de plus relativement aléatoire et risque de se traduire par un comportement complétement incohérent et anarchique du programme.

Mémoire flash : capacité à stocker des données après mise hors tension de l’appareil

Entrées/Sorties PWM : peuvent être utilisées en tant qu’entrée analogique mais seulement pour des données arrivant lentement car il faudrait mettre en place un filtre donc pas idéal dans notre cas.

Adressage : permet de savoir la taille des données que le microcontrôleur peut traiter. Plus il est élevé, plus on pourra traiter de données de grande taille (influe sur la RAM et la capacité de stockage)

## Ecran OLED I2C

### Etat de l’art


Nous avons choisi l’écran OLED 1.3 pouces I2C car il répondait aux nombreux besoins du projet. Par exemple :

- La possibilité de l’utiliser sur une carte de type ESP32 aussi bien sur le plan du software (en utilisant les bibliothèques et l’IDE Arduino) que sur le plan du hardware (surtout côté alimentation).
- Sa taille (3.7 cm) et sa lisibilité, mais aussi sa finesse (seulement 2.7 cm)
- Sa fiabilité
- Son prix très correct (<10€ pièce)
- Son branchement hyper simple et sa facilité d’utilisation, notamment avec la bibliothèque U8g2lib.h qui offre un grand éventail de possibilités.

L’avantage d’un écran OLED (Organic Light-Emitting Diode) par rapport à un écran LCD (Liquid Crystal Display) est dans un premier temps que la technologie OLED permet un rétroéclairage de la dalle qui permet une meilleure lisibilité et une dalle plus fine, dans un second temps l’écran en lui-même est plus petit et donc plus adapté dans un objectif de miniaturisation et de simplicité, enfin, le câblage est beaucoup plus complexe pour un écran LED, avec entre 10 et 16 branchements, ce qui impossible avec l’addition du myoware sur l’ESP32.

### Rôle dans le projet

Le choix d’un écran OLED pour le système Play to Heal permet essentiellement de faciliter et d’améliorer l’expérience utilisateur. En effet, sur ce dernier pourront être affichées les instructions et étapes de la mise en place du système, assurant son bon fonctionnement. Ainsi le personnel de santé ou accompagnant des personnes en situation de handicap gagneront du temps et la personne utilisant la « manette » Play to Heal sera averti en temps réel de son évolution.

Elle permet aussi pour nous de faire des tests directement avec tout le système sans avoir à brancher le système à un ordinateur (qui ne servira, à terme, qu’à afficher le jeu ou le logiciel de rééducation).

### Fonctionnement

Cet écran OLED a seulement besoin de 2 câbles d’alimentation (3.3V), et 2 câbles permettant l’affichage et le stockage d’informations. A Noter que l’écran fonctionne avec beaucoup de librairies différentes. Nous avons décidé d’utiliser la bibliothèque U8g2lib.h pour sa simplicité d’utilisation, sa rapidité et sa lisibilité dans le code.

## Myoware

### Etat de l’art


Lorsque que nous avons repris le projet, l’équipe précédente utilisait des EMG Sensors de la marque Seeed. Ces composants avaient deux inconvénients majeurs : l’imprécision des mesures et l’impossibilité d’obtenir un signal en fréquentiel. Afin de pallier ce problème nous avons effectué une recherche d’autres types de capteurs EMG permettant d’obtenir à la fois un signal de sortie présentant des variations en amplitude, et un autre signal avec des variations en fréquence. C’est à la suite de ces recherches que nous avons trouvé le Myoware, qui présentait ces caractéristiques recherchées et offrait la possibilité de l’alimenter en 3.3V ce qui était également un facteur important (tout notre système étant alimenté avec ce voltage).

Il est également à noter que là où l’EMG Sensor nécessitait l’usage d’électrodes distinctes devant être branchées, le Myoware peut théoriquement être placé directement sur la peau en utilisant ses électrodes intégrées. Nous ne nous en sommes néanmoins pas servis car pouvoir éviter quelques câbles ne nous a pas paru un gain suffisant par rapport au fait de devoir supporter le poids du Myoware et de son alimentation.

### Rôle dans notre projet

Le Myoware (et le Cbale Shield qui y est relié) sont des composants clés de notre dispositif. En effet c’est le Myoware qui procède au traitement des données reçues par les électrodes et qui renvoie vers notre ESP32 un signal relatif à la contraction (ou non) du muscle visé.

Le Myoware peut renvoyer deux types de signaux, le premier présentant une variation de son amplitude en cas de contraction (pin SIG) et le second une variation en fréquence (pin RAW). Nous pouvons utiliser n’importe lequel de ces deux signaux, le SIG étant plus facile à traiter mais le RAW étant plus fiable.

Enfin le Myoware est dans notre dispositif soudé à un Cable Shield. C’est ce dernier qui nous permet d’utiliser des électrodes différentes de celles placées par défaut sur le Myoware. Le Cable Shield est très simple en lui-même, il ne sert que d’extension du Myoware avec une prise jack femelle dédiée aux électrodes.

### Caractéristiques et utilisation

Signaux SIG et RAW
Le signal reçu depuis la pin SIG est plus facile à traiter car il suffit pour cela de définir un seuil dynamique définissant la présence ou l’absence de contraction à partir des valeurs moyenne du signal à l’état contracté et décontracté. Ce seuil est défini durant la procédure d’initialisation de l’appareil, et toute valeur du signal le dépassant sera considérée comme correspondant à une contraction du muscle.

Pour ce qui est du traitement du signal RAW, nous avons mis en place un filtre en cascade afin d’éliminer à la fois le bruit causé par des parasites ainsi que celui d’un muscle standard au repos. Cela signifie que si nous parvenons à observer un signal à la sortie de ce filtre en cascade, alors le muscle visé est contracté.

Alimentation et LED
Le Myoware demande une alimentation standard en 3.3V et une LED verte s’allume lorsque celui-ci est correctement alimenté. Une autre LED rouge s’allume quand le Myoware considère avoir détecté une contraction. Il est toutefois à noter que l’allumage de cette LED est hors de notre contrôle et n’est en aucune façon liée à nos définitions de seuil de contraction. Son allumage n’est donc pas nécessairement une preuve que notre dispositif considère la contraction comme valide.

Placement des électrodes en fonction de leurs couleurs (V11)


## Electrodes

### Etat de l’art


Au moment où notre équipe a repris le projet, le prototype d’alors utilisait des électrodes Seeed allant de paire avec l’EMG Sensor Seeed alors utilisé que nous avons plus tard remplacé par un Myoware (cf. document Myoware pour plus d’informations à ce sujet).

Il est rapidement apparu dans nos recherches que les électrodes en elles-mêmes ne semblaient pas être un élément déterminant dans la qualité de la réception du signal. En effet nous n’avons trouvé nulle part trace de document indiquant un fonctionnement particulier d’un type d’électrodes EMG par rapport à un autre.

Néanmoins, le placement des électrodes, le volume de détection des électrodes et la présence / qualité d’un gel conducteur entre l’électrode et la surface de la peau se sont révélés être des éléments déterminants dans la réception d’un signal musculaire.

### Rôle dans notre projet

Afin de mesurer l’activité musculaire du sujet, nous avons besoin d’électrodes capables de mesurer une différence de potentiel électrique entre deux points d’un système biologique.

Ces électrodes sont placées sur un muscle que le sujet parvient à manipuler correctement, ou au contraire sur un muscle sur lequel il souhaite s’exercer. Une fois les électrodes branchées au reste du système, elles nous permettent de détecter une contraction et de relayer l’information jusqu’à notre dispositif résultant ainsi en une activation du bouton préalablement configuré de la manette adaptative XAC.

Il est à noter que le placement des dites électrodes peut parfois se révéler ardu. En effet une mauvaise disposition de ces dernières peut rendre l’appareil inopérant et il suffit d’une erreur de quelques centimètres pour diminuer gravement la précision de celui-ci.

Pour cette raison, nous indiquerons dans la dernière partie de ce document quelques exemples de placement corrects d’électrodes.

### Placement des électrodes

Les jeux d’électrodes EMG sont composés de 3 électrodes à placer sur le muscle, chacune ayant un rôle particulier. L’une doit être placée au milieu du muscle que l’on veut mesurer et la suivante dans le prolongement de ce muscle, à la fin de ce dernier. C’est la différence de potentiel entre ces deux points qui va permettre à l’EMG Sensor auquel ces électrodes sont reliées de mesurer l’occurrence d’une contraction. On place enfin une troisième électrode sur une surface osseuse ou musculaire mais non-adjacente. Cette dernière électrodes va servir de référence afin de diminuer l’impact du bruit sur la qualité de la réception. Il est à noter qu’un placement relativement permissif peut être fait sur le biceps, en utilisant le triceps comme référence.


### Volume de détection des électrodes et gel conducteur

Au bout de chaque électrode d’un jeu, il est nécessaire d’attacher une « tête » adhésive permettant la réception du signal électrique. La taille de cette tête et sa lubrification sont des éléments clés d’une bonne réception de signal. Une tête plus petite permettra un placement plus précis sur des plaques motrices de taille réduite, permettant ainsi d’augmenter le nombre de muscles avec lesquels le dispositif peut être utilisé. En contrepartie, il est alors nécessaire de savoir exactement où placer les électrodes sous peine d’être incapable d’utiliser l’appareil. Mais même une fois correctement placées, les électrodes peuvent encore rencontrer une dernière difficulté : l’impédance à la surface.

Le signal électrique généré par une contraction musculaire est de faible amplitude (10 mV). Les électrodes doivent donc avoir une résistance minimale afin de détecter ce signal. Pour les cas les plus délicats, il est possible de réduire l’impédance à la surface de la peau en abrasant la surface de celle-ci et en la nettoyant à l’aide d’alcool à friction. On peut également appliquer un gel conducteur spécial, permettant ainsi d’augmenter encore la qualité de la réception par les électrodes

### Fonctionnement

Le signal EMG résulte de la superposition de l’ensemble des potentiels d’action des unités motrices situées dans le volume de détection des électrodes, il permet ainsi de détecter des contractions musculaires. En effet le corps humain est généralement un bon conducteur électrique. Ainsi, les signaux électriques issus d’une contraction musculaire ont tendance à se propager jusqu’à la surface de la peau ce qui permet à des électrodes de détecter ces contractions.

Il est à noter que des parasites peuvent être détectés lors de mesures avec des électrodes. Ils peuvent être dus à un mauvais placement des électrodes, à la présence d’un corps étranger entre les électrodes et la peau ou à un mouvement dans les câbles des électrodes. Pour réduire ce bruit, différentes méthodes ont été mises en place, expliquées dans le document sur le Myoware.

## Manette, Jack, Transistor

### Etat de l’art

La connexion en digital (pas analogique) à la manette se fait par le biais de câbles JACK 3.5 (stéréo standard). Afin de cliquer un bouton, il faut que le tip et le sleeve du jack branché à ce bouton soient connectés. Exemple ci-dessous :


Le switch permet de cliquer ou non le bouton associé. Ce switch sera réalisé par un transistor, c’est un composant qui permet principalement de contrôler les signaux électriques en les amplifiant ou en servant d’interrupteur. Il peut aussi servir de redresseur de signal ou permettre de stabiliser la tension voire la détecter.

Dans le cadre de notre projet, nous avons choisi le transistor NPN (PN2222) pour les raisons suivantes :

- De petite taille
- Peut fonctionner en basse tension
- Très bon marché
- Faible impédance de sortie
- Longue durée
- Actions spontanées

Le PNP a les mêmes avantages mais est plus lent.

### Rôle dans le projet

Dans le cadre de notre projet, nous allons utiliser des transistors pour effectuer le switch qui permet de cliquer le bouton ou non. Nous utilisons maintenant un NPN Transistor (le PN2222). Afin d’éviter de devoir couper le bout du jack male que nous voulons connecter au transistor, nous utilisons une prise jack femelle.

### Fonctionnement

### Transistor bipolaire (BJT)

Composé de 3 couches de semi-conducteurs dopées positivement et négativement. La couche P possède un manque d’e- et N un excès d’e-.

Deux types de BJT possibles NPN et PNP comprenant :

- Une base (B) : connectée à un potentiel négatif pour le NPN (positif PNP)
- Un émetteur (E)
- Un collecteur (C) : connecté à un potentiel positif pour le NPN (négatif PNP)

En sortie E le sens du courant est différent. Positif en NPN et négatif en PNP.


Régimes de fonctionnement :

1. Passant
- Le courant B permet de laisser passer plus ou moins de courant entre C et E.
- Une amplification du signal électrique est possible.
- Entre C et E c’est un fil.
2. Régime saturé
- Laisse passer la totalité du courant d’alimentation.
3. Bloquant
- Aucun courant ne parcourt le transistor, l’interrupteur est ouvert

Le transistor permet donc de servir d’interrupteur commandé avec une faible énergie de commande.


Fiche technique du transistor PN2222 :


Pour le transistor PN2222, la tension max est de 40 V et la tension de seuil est

## Bibliographie

Manette adaptative : https://www.xbox.com/fr-FR/accessories/controllers/xbox-adaptive-controller

Transistor : https://www.amazon.fr/Adafruit-NPN-Bipolar-Transistors-PN2222/dp/B00XW2OK7M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 (https://www.amazon.fr/Adafruit-NPN-Bipolar-Transistors-PN2222/dp/B00XW2OK7M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)

Jack male: https://www.gotronic.fr/art-cordon-jack-ca35s05-15030.htm

Electrodes: https://www.gotronic.fr/art-cordon-cab-12970-26243.htm

ESP32: https://www.gotronic.fr/art-module-nodemcu-esp32-28407.htm

OLED: https://www.gotronic.fr/art-afficheur-oled-1-3-i2c-tf051-28512.htm#complte_desc

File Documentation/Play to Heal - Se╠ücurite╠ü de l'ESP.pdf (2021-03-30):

# Sécuriser l’ESP32

## Table des matières

## Sécurité physique

### Quelles attaques et quels risques ?

Tout d’abord, il faut savoir qu’aujourd’hui en IoT, tous les appareils sont vulnérables si un accès physique un possible. Il ne s’agit ensuite qu’une question de temps et de coût concernant la solution d’attaque.
Bien que l’ESP32 soit assez sécurisé physiquement, les attaques les plus courantes et les plus embêtantes concerne la vulnérabilité d'injection de fautes (Fault Injection Vulnerability). Le but de l’attaquant est de pouvoir lire et modifier des informations telles que le micro-logiciel et les données stockées dans la mémoire flash de l’appareil. De ce fait, il peut tout à fait démarrer un micro-logiciel non-approuvé et dangereux.
Si l’ESP32 n’est pas sécurisé correctement, n’importe qui peut démarrer un micro-logiciel sur la carte à l’aide d’un simple câble USB et d’un ordinateur. Cependant, si des mesures ont été prises, il faut faire preuve de beaucoup plus d’investissement en termes de coût et de temps. En effet, il existe diverses méthodes physiques pour une injection de défaut, telles que des fluctuations de tension ou d'horloge soigneusement chronométrées, une variation de température externe, une irradiation laser ou l'utilisation de champs magnétiques puissants. Pour réaliser l’investissement nécessaire si le système est sécurisé correctement, il est important de noter les points suivants concernant l'attaque :
- Elle nécessite un accès physique afin que des pièces puissent être retirées de la carte de circuit imprimé ou du module. Les traces de circuits imprimés peuvent également devoir être coupées ou modifiées avant d'être connectées à l'équipement de l'attaquant.
- L'équipement de tension parasite de l'attaquant doit être connecté à des broches d'alimentation particulières de l’ESP32 afin que des tentatives répétées puissent être faites pour introduire une fluctuation de tension correctement synchronisée.

### Comment bien sécuriser l’ESP32 ?

Afin de rendre le plus difficile possible une attaque concernant la vulnérabilité d’injection de fautes, il faut mettre en place deux mesures de sécurité : secure boot et flash encryption.
Lorsque le secure boot est activé, le chargeur de démarrage logiciel (software bootloader) génère et programme une clé de démarrage sécurisé « unique par périphérique » dans la mémoire eFUSE (mémoire interne à l’ESP32) lors du premier démarrage. Après cela, les potentiels futurs attaquants ne pourront seulement récupérer que la clé public avec laquelle il est impossible de récupérer la clé privée. Or, chaque démarrage de micro-logiciel nécessite une vérification de la clé privé. Ainsi, sans cette dernière, il est impossible de modifier le code pour démarrer un micro-logiciel malveillant.

Concernant le flash encryption, le même procédé est utilisé et il faut une clé privé pour pouvoir accéder aux données de la mémoire flash.
À noter qu’il est possible d’utiliser le secure boot sans le flash encryption mais pour avoir un environnement sécurisé, il vaut mieux utiliser les deux.

## Sécurité à distance

L’ESP32 permet nativement d’utiliser des fonctionnalités Wifi ou Bluetooth. Ces dernières présentent différentes vulnérabilités pouvant potentiellement permettre à une personne mal intentionnée d’attaquer l’appareil.
La conséquence la plus commune de ces attaques est le crash de l’ESP32, mais certaines vulnérabilités permettent à l’attaquant de rejouer, décrypter ou déguiser certaines frames via un access point rogue. On peut retrouver le détail de plusieurs de ces vulnérabilités sur le site de la National Vulnerability Database, que ce soit par rapport aux crashs (CVE-2019-12586) ou à l’interception des frames (CVE-2019-12587). Cette dernière vulnérabilité est d’ailleurs classée en score de dangerosité HIGH. Néanmoins, ces deux vulnérabilités, à l’image d’autres pouvant être trouvées sur Internet, profitent de faiblesses dans le protocole EAP d’authentification. Or, ce protocole est utilisé dans le cadre d’une connexion sécurisé Wifi et implique donc que le Wifi soit activé sur notre machine. Après consultation de différents sites, il apparaît que le Wifi est par défaut désactivé et qu’il est nécessaire d’intégrer des librairies particulières (notamment <Wifi.h>) afin de s’en servir. Notre ESP32 n’utilisant pas ces librairies, nous devrions être à l’abri d’attaques visant des vulnérabilités du réseau Wifi.
De même, nous devrions être à l’abri des vulnérabilités liées à l’utilisation du Bluetooth (voir source).

## Que reste-il faire ?

Comme vous avez pu le voir, notre système n’est pas vulnérable aux attaques à distance. Il ne reste donc que les attaques physiques que nous n’avons malheureusement pas pu mettre en place cependant nous avons une piste. En effet, pour il se pourrait que le secure boot et la flash encryption soit assez simple à mettre en place.
- Il | suffirait | d’installer | cette | librairie | sur | vscode :
https://marketplace.visualstudio.com/items?itemName=espressif.esp-idf-extension
- Puis de regarder le tutoriel ici : https://docs.espressif.com/projects/esp-idf/en/latest/esp32/security/secure-boot-v1.html (https://docs.espressif.com/projects/esp-idf/en/latest/esp32/security/secure-boot-v1.html)
Le problème auquel nous avons dû faire face est la mise à jour de l’extension. Celle-ci ne s’installait pas comme expliqué sur le premier lien et de ce fait son utilisation était compromise. Les alternatives trouvées étaient bien trop compliquées ou trop risquées par rapport au temps et au nombre de composant disponible que nous avions car elles impliquaient de coder au cœur de l’ESP32 impliquant un potentiel dysfonctionnement si une erreur était commise.

## Possibilité d’amélioration, alternatives

L’évolution du projet peut nous amener à considérer l’utilisation des fonctionnalités WIFI ou Bluetooth de l’ESP32 afin de réduire la taille du dispositif par exemple.
Le problème de la sécurisation du produit se pose. Avec un échange d’informations par Bluetooth ou WIFI, il est possible de nuire au fonctionnement de l’appareil, les menaces les plus fréquentes étant le déni de service, les écoutes et analyses passives, l’interception de données ou encore les attaques actives qui modifieraient le flux d’information. Il faudra donc faire un choix dans les différents mécanismes de protections possible en fonction de la finesse voulue et de ce qui est faisable avec notre ESP32 (voir les mécanisme de protections dans les sources).
En plus de ces sécurités, il faudrait également éviter les « mauvaises pratiques » et ainsi désactiver le Bluetooth lorsqu’il n’est plus nécessaire, ne pas répondre à une demande de connexion inattendue ou éviter les protections par défaut avec des codes PINS trop simples. Si jamais vous en ressentez le besoin, un tuto Bluetooth avec ESP32_BLE_Arduino est disponible dans les sources.
Espressif a annoncé en Décembre 2020 un nouvel Esp : l’ESP32-C3, un microcontrôleur WIFI et BLE 5.0 dans lequel sont intégrés plusieurs mécanismes de sécurité. Ce microcontrôleur pourrait être une bonne alternative pour passer sur un signal sans fil, qu’il soit par WIFI ou Bluetooth. Il est équipé d’un démarrage rapide et sécurisé sur les applications de confiance (RSA-3072), d’un cryptage de mémoire flash (AES-128-XTS), d’un périphérique de signature numérique et d’un word controller (deux environnements d’exécution différents). On peut aussi penser à passer sur un système d’électrodes sans fil, qui seraient parfaitement prises en charge par ce microcontrôleur. Veuillez voir sur le site pour une demande de commande (site en sources).

## Bibliographie

https://www.espressif.com/en/news/ESP32_FIA_Analysishttps://docs.espressif.com/projects/esp-idf/en/latest/esp32/security/secure-boot-v1.htmlhttps://www.esp32.com/vie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 : (ESP_igrr est un administrateur du site)

https://www.securiteinfo.com/attaques/phreaking/securite_reseaux_sans_fil_Bluetooth.shtml

http://tvaira.free.fr/bts-sn/activites/activite-ble/activite-ble-esp32.html

https://www.espressif.com/en/products/socs/esp32-c3

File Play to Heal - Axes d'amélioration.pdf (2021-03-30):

1

# Axes d’amélioration du projet pour de futures équipes

## Table des matières

### Introduction | 1

### Améliorations simples | 1

### Améliorations complexes | 1

## Introduction

Comme nous avons pu le dire tout au long de ce document, nous sommes fiers du travail que nous avons fourni et du résultat auquel nous sommes parvenus. Nous pensons néanmoins que certaines améliorations ou innovations techniques pourraient être apportées au projet par de futures équipes, c’est pourquoi nous allons vous présenter quelques-unes de ces idées.

## Améliorations simples

La première d’entre elles est l’ajout d’un système de sélection de la difficulté. En effet dans la version actuelle du dispositif, les valeurs moyennes décontracté et contracté sont établies à chaque allumage du boitier. Cela nous permet d’établir un seuil de contraction égal à la valeur décontractée + environ 30% de l’écart entre les deux moyennes. Ce système nous permet de facilement détecter une contraction et la distinguer du bruit dû à l’activité standard d’un muscle sans forcer l’utilisateur à contracter son muscle au maximum.
Toutefois si une utilisation dans un objectif thérapeutique était faite, il serait probablement nécessaire de pouvoir modifier ce pourcentage de 30% afin d’augmenter ou diminuer la difficulté d’activation d’un bouton. On peut par exemple imaginer la fixer à 10% pour un muscle commençant tout juste la rééducation, et 40% pour un muscle presque rétabli. Il s’agit d’une fonctionnalité dont l’ajout serait relativement trivial mais que nous pensons néanmoins potentiellement très utile.

## Améliorations complexes

Les améliorations suivantes sont plus complexes à implémenter, mais nous les pensons néanmoins particulièrement utiles.

Tout d’abord, nous estimons nécessaire l’ajout à notre dispositif d’une dimension de sécurité. En effet même si l’appareil n’est pas connecté à quoique ce soit via Bluetooth ou Wifi, il reste vulnérable à des attaques physiques et doit donc en être protégé au maximum. Un document annexe a d’ailleurs été rédigé à ce propos et nous vous invitons à suivre les recommandations qu’il contient.
Toujours sur le sujet du Bluetooth, nous avons remarqué que le nombre de fils impliqués dans l’utilisation de notre dispositif avec plus de 2 muscles devient rapidement encombrant. La meilleure solution pour y faire face serait de passer d’électrodes filaires à des électrodes connectées au boîtier en Bluetooth. Les têtes d’électrodes pourraient être intégrées dans un straps (ou un équivalent) et un simple microcontrôleur alimenté par une pile bouton connecté à un module Bluetooth

2

transmettrait les informations des électrodes au boitier principal. Un certain nombre d’élément devraient être pris en compte tels que l’alimentation, le poids, etc. mais nous pensons qu’il s’agira surement d’une étape nécessaire afin de professionnaliser le produit.

Une autre étape qui sera surement nécessaire sera de se séparer du Myoware. En effet il s’agit de l’élément le plus cher de notre boitier, ainsi que d’un composant clé de notre système. Pour ces deux raisons, il serait préférable de concevoir nous-même une alternative (informatique ou électronique) remplaçant le Myoware. Cela nous permettrait de réduire grandement nos coûts de production (le Myoware représentant presque 50% du prix du boîtier) mais également d’avoir un contrôle complet sur l’acquisition du signal provenant des électrodes ainsi que son traitement et son interprétation. Cela nous éviterait aussi, dans une moindre mesure, d’être dépendant de l’entreprise Sparkfun dans la production de nos boitiers Play To Heal.

Enfin nous avons envisagé une dernière amélioration, beaucoup plus complexe que les autres à notre avis. Celle-ci n’est pas nécessaire dans le cadre d’utilisation actuel de notre dispositif mais pourrait élargir le champs d’utilisation de Play To Heal et d’offrir plus d’autonomie aux utilisateurs. Il s’agit en effet de ne plus utiliser les capteurs EMG uniquement pour détecter une contraction, mais plutôt mettre leurs données en commun afin d’obtenir une simulation de l’état du bras de l’utilisateur. Cela nous permettrait (avec un nombre de capteurs réduit) de détecter à la fois des contractions mais aussi des torsions, des élévations, extensions... Nous pourrions ainsi étendre la variété des mouvements pouvant être interprétés et donc le nombre de bouton pouvant être contrôlés par l’utilisateur. La conception d’un réseau de neurones pourrait notamment être envisagée afin de proposer une solution à cet axe d’amélioration.
Un premier test de connexion Bluetooth entre le boitier et une carte Raspberry Pi 4B a d’ailleurs été effectué avec un échange d’information fonctionnel entre les deux cartes. On peut donc imaginer que le boitier renverrait les données de contractions vers la Raspberry qui, contenant un réseau de neurone développé en Python, serait à même d’identifier la nature du mouvement effectué par l’utilisateur et renvoyer l’information vers le boitier. Dans l’éventualité d’une utilisation de cette solution combinée aux électrodes Bluetooth, la Raspberry pourrait même simplement remplacer l’ESP32 actuellement utilisé. En effet la Raspberry n’est, contrairement à ce dernier, pas capable d’effectuer des lectures de signaux analogiques.

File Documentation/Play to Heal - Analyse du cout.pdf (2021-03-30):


1

# Analyse du cout

## Table des matières

### Introduction | 1

### Coût pour un boitier | 1

### Coût par muscle ajouté | 2

### Coût d’impression 3D | 2

## Introduction

Dans l'optique d'obtenir un prototype fonctionnel, nous avons réalisé des commandes tout au long de l'année afin d'obtenir les éléments dont nous avions besoin. Microsoft, notre partenaire sur ce projet, a entièrement pris en charge ces commandes. Le but de ce prototype étant de servir de modèle dans le cas d'une industrialisation du produit, nous avons répertorié les éléments nécessaires à son fonctionnement ainsi que leur prix. Le matériel que nous avons éliminé au fur et a mesure de nos tests ne figure pas dans cette étude. On y trouve seulement ce qui est nécessaire pour la version « finale » de notre produit.

## Coût pour un boitier

Un boitier fonctionnel pour un muscle coute environ 150€. Ce prix comprend tout le matériel électronique nécessaire au traitement du signal reçu des muscles par les électrodes et son acheminement jusqu’à la manette adaptative XAC ainsi que des éléments du boitier comme la vitre transparente, l’écran OLED, le porte pile et les différentes fixations. Si le prix du boitier semble élevé, c’est d’abord parce que nous avons commandé chaque élément au détail, dans le cas d’une industrialisation, un achat en gros permettrait de réduire grandement ces dépenses.

Détail du prix pour un boitier (total en €) :


2

## Coût par muscle ajouté

Il est également important de noter que dans un boitier nous avons la place d’ajouter jusqu’à 4 muscles en plus de celui déjà compté dans le boitier de base. Pour chaque muscle supplémentaire, il faut compter environ 45€, ce qui, encore une fois, est une estimation à la hausse due à l’achat au détail de notre matériel.

Détail du prix par muscle additionnel

## Coût d’impression 3D

Pour ce qui est du boitier imprimé en 3D que nous avons modélisé, nous avons d’abord réalisé un devis en ligne pour son impression chez Sculpteo (voir annexe). Il fallait compter plus de 300€ hors taxes pour l’impression complète ce qui était beaucoup trop élevé. Nous avons donc imprimé gratuitement le boitier au Fab-Lab du Pôle Léonard de Vinci, ce qui explique pourquoi il n’est pas présent dans cette étude.

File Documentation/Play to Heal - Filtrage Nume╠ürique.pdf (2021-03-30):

# Filtrage


## Table des matières

## Etat de l’art

Il existe deux types de filtres numériques.

Tout d’abord les filtres à Réponse Impulsionnelle Finie (RIF). Comme son nom l’indique, un filtre à réponse impulsionnelle finie est un filtre dont la réponse impulsionnelle est de durée finie. Un filtre numérique RIF est caractérisé par une réponse uniquement basée sur un nombre fini de valeurs du signal d'entrée.

Or, pour le projet Play to Heal, nous devons analyser les valeurs des signaux envoyés par les électrodes en direct et de manière continue et instantanée. Par conséquent, le nombre de valeurs du signal d’entrée est potentiellement infini.

En conclusion, nous ne pouvons pas prendre en compte ce type de filtre pour la réalisation de notre projet.

Le choix se tourne alors vers les filtres à réponse impulsionnelle infinie. Ces filtres sont récursifs et se rapprochent des filtres analogiques traditionnels. Ils nécessitent moins d’opérations pour les implémenter et consomment moins de mémoire.

## Rôle dans le projet

Pour trouver le filtre qui correspond le mieux à notre besoin, nous avons d’abord mené une revue de la littérature scientifique sur le sujet.

Après plusieurs publications étudiées, nous avons décidé de traiter le signal RAW du Myoware avec un filtre de Butterworth afin d’avoir la main mise sur le signal renvoyé vers la manette adaptative.

Ce signal filtré manuellement nous offre plus de possibilités que le signal SIG, notamment l’opportunité de fixer des « seuils de contractions » afin de permettre plus d’actions de la manette.

## Test et mise en place du filtre

Nous avons réalisé, dans un premier temps, l’entièreté de nos tests sur MatLab. En effet, ce logiciel se prêtait particulièrement bien à la récupération, traitement et analyses des signaux.

Le signal RAW récupéré par le Myoware est un signal brut de l’EMG. Cela signifie que le signal n’est pas traité et filtré au préalable comme avec le signal SIG. Ce signal est donc bruité (interférence, notamment dû à la prise de mesure) et comporte plusieurs fréquences inutiles.

Ci-dessous, un exemple de signal RAW simplement affiché sur MatLab.

Exemple de signal RAW (traité) vs SIG.


Nous avons dans un premier temps récupéré les valeurs numériques du signal pour pouvoir recréer l’EMG sur Matlab. Nous cherchions à déterminer des fréquences de coupure optimales afin d’isoler au mieux la contraction. Pour se faire, nous avons utilisé la fonction ffshift() de Matlab sur le signal RAW pour le passer en fréquentiel et ainsi avoir une vision de ce qui se passe dans ce domaine-là. Notre choix s’est ainsi porté sur un filtre de Butterworth d’ordre 4 passe bande [2Hz – 40Hz]. Une fois le signal filtré et la contraction isolée, nous l’avons redressé et intégré afin d’obtenir son enveloppe. Pour cela la valeur du signal a été mise au carré (il est possible de calculer sa valeur absolue aussi). L’intégration est réalisée avec la technique du RMS (Root Mean Square). Selon la valeur du RMS, l’enveloppe sera plus ou moins fidèle au signal. Le traitement obtenu sur Matlab avec un RMS de 150 ressemble à cela :

Le traitement sur Matlab correspond à ce que l’on cherchait à faire. L’idée était ensuite d’implémenter le même filtre sur l’IDE Arduino pour que l’ESP32 puisse traiter en temps réel le signal RAW du Myoware. Après de nombreuses recherches, nous n’avons pas trouvé de librairies Arduino nous permettant de réaliser un filtre de Butterworth de type passe-bande. Nous avons donc décidé de créer notre propre filtre en utilisant deux passe-haut en cascade. La librairie utilisée est celle de tttapa. Voici un lien vers son Git-Hub : https://github.com/tttapa/Arduino-Filters/actions

Le résultat obtenu avec ce « filtre maison » est moins performant que le filtre implémenté sur Matlab, cependant les tests réalisés par la suite en situation réelle nous ont permis d’attester de sa fiabilité vis-à-vis de nos attentes.

## Conclusion

Filtrer le signal RAW du Myoware nous permet d’avoir la main mise sur le signal qu’on récupère. Grâce à l’ESP32, le filtre de Butterworth numérique isole efficacement la contraction musculaire de l’utilisateur et le traitement fait par la suite assure l’envoie d’un signal simple vers la manette. L’avantage de ce procédé est qu’on peut décider de l’allure du signal en modifiant certains paramètres comme la valeur du RMS. Cela peut être une alternative intéressante au signal SIG qui fonctionne plus dans un mode binaire (repos : 0/contraction : 1).

## Annexe

Voici les informations complémentaires concernant le travail de recherche et ses problématiques.

Problématique d’un filtre d’ordre 4 en 0 Problème d’amortissement en 0 due au fait qu’un filtre de butterworth nécessite les valeurs précédentes à celles qu’il modifie au fur et à mesure. Solution: mettre manuellement les premières valeurs à 0.


Redressement et enveloppe du signal

Afin de répondre à notre problématique qui était de pouvoir fixer des seuils (dynamiques) de contraction ; et pour cela nous avons centré et redressé le signal avant de tracer son enveloppe.

Le choix de l’enveloppe est déterminant par rapport à la précision et doit être déterminé judicieusement.


Affirmation/Confirmation de nos résultats avec un 2e
signal présentant 3 périodes de repos et 2 contractions maximale. Questionnement les fréquences de coupures sont-elles propres à chaque individu ? Découverte : La pratique d’une activité sportive avant mesure n’affecte pas les fréquences de coupure ni le signal en lui-même.


Traduction du filtre sur Arduino, malheureusement les librairies ne sont pas aussi efficaces que sur MatLab. Exemples sur 2 signaux traités sur ESP 32 vs. MatLab.


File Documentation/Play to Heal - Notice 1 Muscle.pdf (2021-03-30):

# Play to Heal

# Guide de prise en main rapide du boîtier Play to Heal (un muscle)

## Contenu du coffret

- Le boîtier play to heal (un muscle)
- La manette Microsoft adaptative controller
- Jeu de trois électrodes
- Prise jack mâle-mâle
- Deux piles AA
- Un bandage élastique

# Le boîtier et ses accessoires


La manette Microsoft adaptative controller

Piles AA | x 2 | Jeu de trois électrodes

Prise jack mâle-mâle

Bandage élastique | 3

# Première utilisation

Etape 1 Alimentation du boîtier

1. Faites coulisser le capuchon situé en haut du boîtier.
2. Insérez les deux piles AA dans le supporte piles.
3. Refermez le capuchon en le faisant coulisser dans le sens inverse.
4. Appuyez sur l’interrupteur et vérifier que l’écran s’allume. Eteignez le boîtier.

Etape 2 Branchement

1. Branchez la manette Microsoft Adaptative Controller à un ordinateur ou à une console de jeu Xbox.
a. Pour un ordinateur, vous trouverez toutes les informations pour configurer la manette Xbox Adaptative Controller
| ici : https://support.xbox.com/fr-FR/help/account-profile/accessibility/connect-adaptive-controller-to-pc
b. Pour une Xbox ONE, vous trouverez toutes les informations pour configurer la manette Xbox Adaptative Controller
| ici : https://support.xbox.com/fr-FR/help/account-profile/accessibility/connect-adaptive-controller-to-xbox-one
2. Branchez le boîtier Play to Heal à la manette Microsoft Adaptative Controller à l’aide des prises jack mâle- mâle en fonction des boutons que vous souhaitez actionner.

Attention : vérifiez que vous branchez le câble jack sur la bonne prise du boîtier Play to Heal (dans un coin).
Idem pour la manette Microsoft Adaptative Controller, veillez à brancher le câble sur la prise associée au bouton que vous souhaitez utiliser.
3. Branchez les électrodes au boîtier à l’aide des prises jack dédiées.

Attention : vérifiez que vous branchez le câble jack sur la bonne prise du boîtier Play to Heal (au milieu).

Etape 3 Placement des électrodes

1. Choisissez le muscle que vous souhaitez utiliser pour jouer.
2. Nettoyez votre peau au savon à l’aide d’un gant exfoliant. Rincez bien. Il est possible d’utiliser un gel électrolytique pour faciliter le positionnement des électrodes.
3. Veuillez faire appel à un professionnel de la santé pour le placement des électrodes. Un exemple du placement correct des électrodes pour le bras est fourni en annexe.

Attention : L’exemple fourni en annexe ne se substitue pas à l’aide d’un professionnel.

4. Une fois les électrodes placées, enroulez le bandage élastique par-dessus afin de les maintenir en place.

Etape 4 Allumage du boîtier

1. Allumez le boitier à l’aide de l’interrupteur.
2. Veuillez suivre les instructions sur l’écran.
3. Lancez le jeu de votre choix.

# Profitez !

# Annexe


Electrodes actives

Les deux électrodes actives sont placées dans le sens des fibres du muscle choisi afin d’enregistrer son activité.

Electrode de référence

L’activité du muscle choisi est mesurée par rapport à l’activité au niveau de l’électrode de référence. L’électrode de référence n’est donc pas située sur le muscle choisi. Pour le biceps, elle peut être placée au niveau du poignet.

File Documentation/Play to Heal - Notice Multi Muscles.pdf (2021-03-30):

# Play to Heal

# Guide de prise en main rapide du boîtier Play to Heal (multi muscle)

## Contenu du coffret

- Le boîtier play to heal (multi muscle)
- La manette Microsoft adaptative controller
- Jeu de trois électrodes
- Prise jack mâle-mâle
- Deux piles AA
- Un bandage élastique

# Le boîtier et ses accessoires


La manette Microsoft Adaptative Controller

Piles AA | x 2 | Jeu de trois électrodes

Prise jack mâle-mâle

Bandage élastique | 3

# Première utilisation

Etape 1 Alimentation du boîtier

1. Faites coulisser le capuchon situé en haut du boîtier.
2. Insérez les deux piles AA dans le supporte piles.
3. Refermez le capuchon en le faisant coulisser dans le sens inverse.
4. Appuyez sur l’interrupteur et vérifier que l’écran s’allume. Eteignez le boîtier.

Etape 2 Branchement

1. Branchez la manette Microsoft Adaptative Controller à un ordinateur ou à une console de jeu Xbox.
a. Pour un ordinateur, vous trouverez toutes les informations pour configurer la manette Xbox Adaptative Controller
| ici : https://support.xbox.com/fr-FR/help/account-profile/accessibility/connect-adaptive-controller-to-pc
b. Pour une Xbox ONE, vous trouverez toutes les informations pour configurer la manette Xbox Adaptative Controller
| ici : https://support.xbox.com/fr-FR/help/account-profile/accessibility/connect-adaptive-controller-to-xbox-one
2. Branchez le boîtier Play to Heal à la manette Microsoft Adaptative Controller à l’aide des prises jack mâle- mâle en fonction des boutons que vous souhaitez actionner.

Attention : vérifiez que vous branchez le câble jack sur la bonne prise du boîtier Play to Heal (dans un coin, voir annexe).
Idem pour la manette Microsoft Adaptative Controller, veillez à brancher le câble sur la prise associée au bouton que vous souhaitez utiliser.
3. Branchez les électrodes au boîtier à l’aide des prises jack dédiées.

Attention : vérifiez que vous branchez le câble jack sur la bonne prise du boîtier Play to Heal (au milieu, voir annexe).

Etape 3 Placement des électrodes

1. Choisissez les muscles que vous souhaitez utiliser pour jouer.
2. Nettoyez votre peau au savon à l’aide d’un gant exfoliant. Rincez bien. Il est possible d’utiliser un gel électrolytique pour faciliter le positionnement des électrodes.
3. Veuillez faire appel à un professionnel de la santé pour le placement des électrodes. Un exemple du placement correct des électrodes pour le bras est fourni en annexe.

Attention : L’exemple fourni en annexe ne se substitue pas à l’aide d’un professionnel.

4. Une fois les électrodes placées, enroulez le bandage élastique par-dessus afin de les maintenir en place.

Etape 4 Allumage du boîtier

1. Allumez le boitier à l’aide de l’interrupteur.
2. Veuillez suivre les instructions sur l’écran.
3. Lancez le jeu de votre choix.

# Profitez !

# Annexe


Electrodes actives

Les deux électrodes actives sont placées dans le sens des fibres du muscle choisi afin d’enregistrer son activité.

Electrode de référence

L’activité du muscle choisi est mesurée par rapport à l’activité au niveau de l’électrode de référence. L’électrode de référence n’est donc pas située sur le muscle choisi. Pour le biceps, elle peut être placée au niveau du poignet.

# Annexe


Branchement électrodes
Branchement vers manette

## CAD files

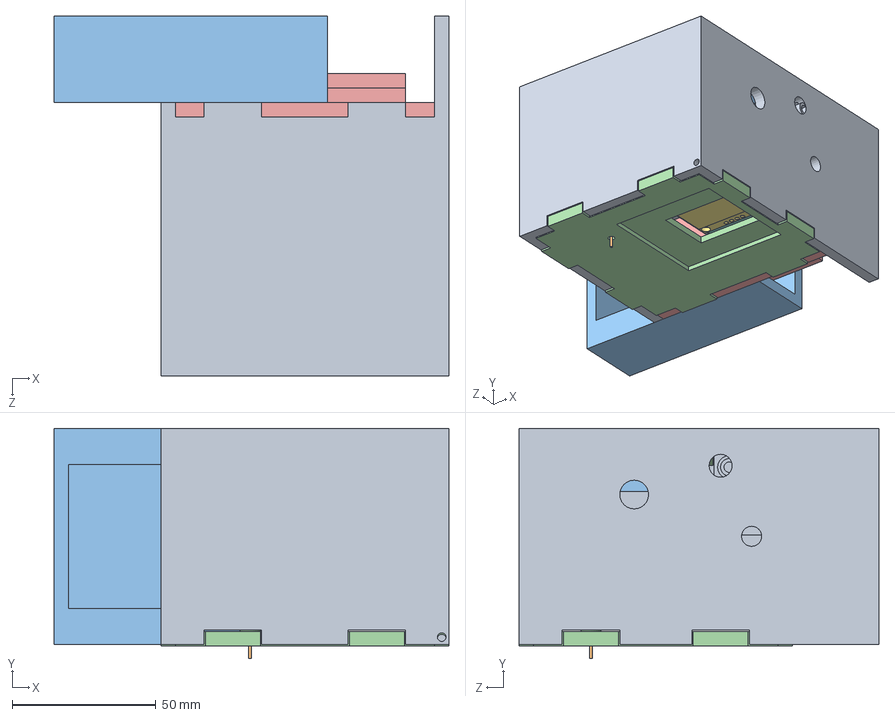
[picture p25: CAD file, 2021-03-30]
3D modeling/Monomuscle/SolidWorks/boitier_assemble╠ü.SLDASM
137.1 x 80.0 x 125.0 mm
piece principal
PCB Myoware
Myoware_Shield
Myoware_Capteur
ESP32
PCB ESP32
Ecran_LCD
PCB OLED
Jack_femelle
bouton_pressoir
capuchon
face oled
support porte pile

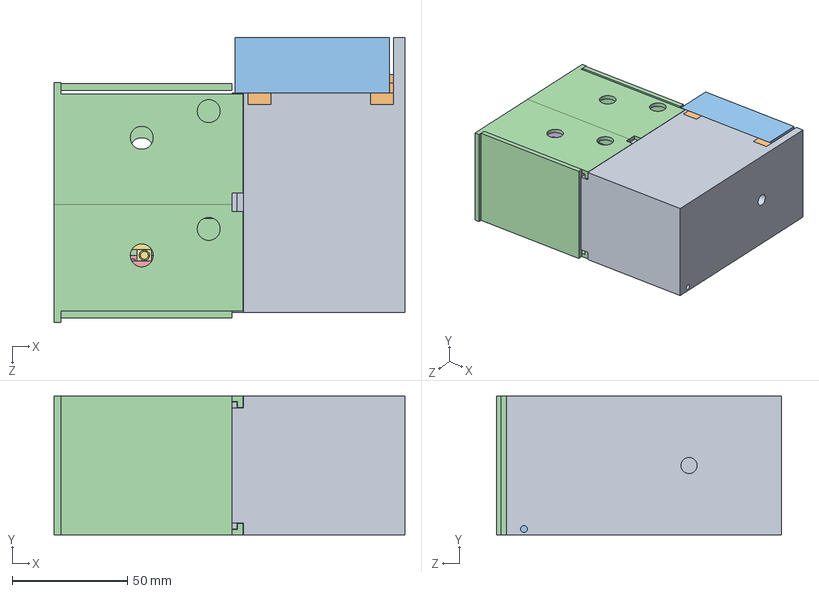
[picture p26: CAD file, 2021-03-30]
3D modeling/Multimuscles/SolidWorks/boitier extensible.SLDASM
152.0 x 60.0 x 123.3 mm
piece principale 2
support porte pile 2
face oled 2
extension x 2
Myoware_Capteur x 2
PCB Myoware x 2
Myoware_Shield x 2
Jack_femelle x 2
PCB OLED
Ecran_LCD
capuchon 2b
top_extension x 2

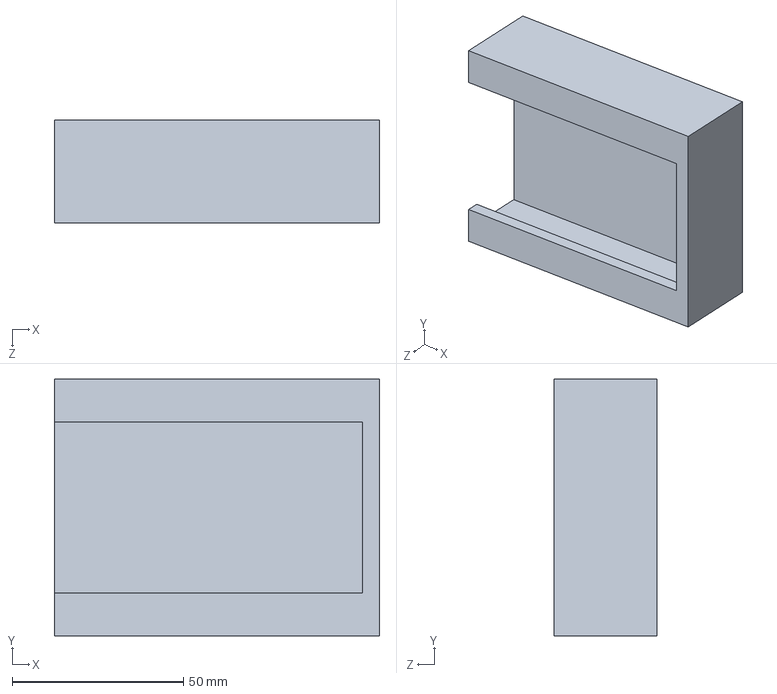
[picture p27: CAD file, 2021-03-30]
3D modeling/Monomuscle/SolidWorks/capuchon.SLDPRT
95.0 x 75.0 x 30.0 mm

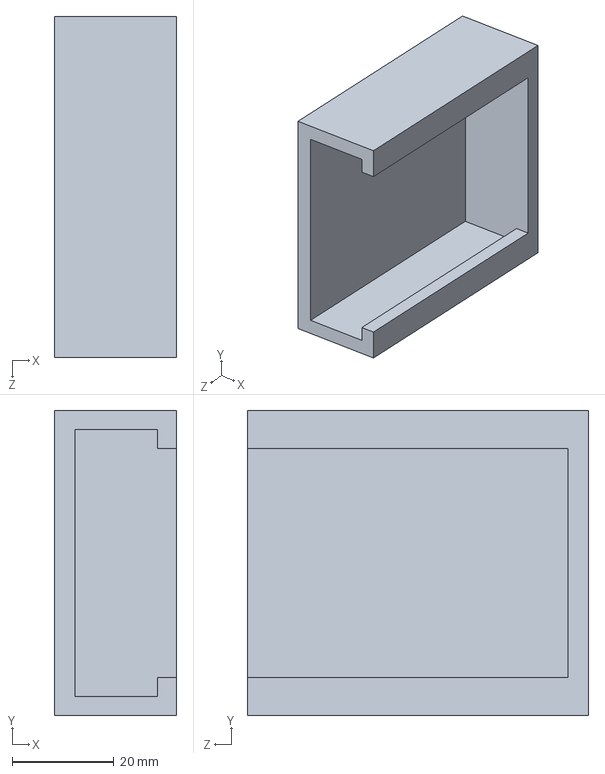
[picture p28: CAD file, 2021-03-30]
3D modeling/Multimuscles/SolidWorks/capuchon 2.SLDPRT
24.0 x 60.0 x 67.0 mm

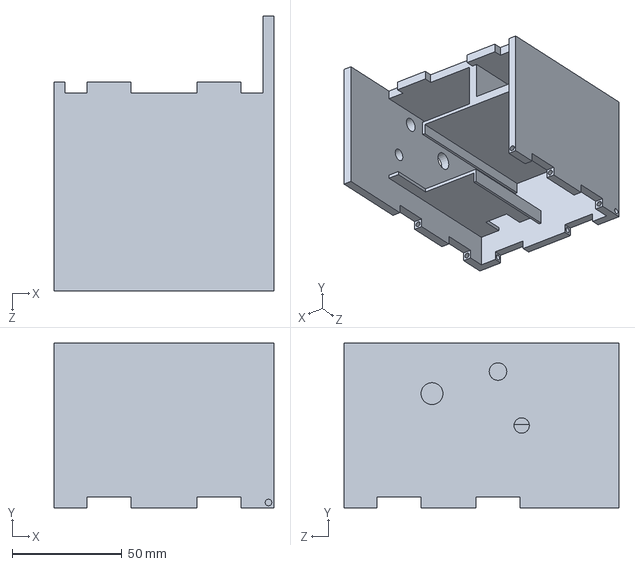
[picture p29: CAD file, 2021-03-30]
3D modeling/Monomuscle/SolidWorks/piece principal.SLDPRT
100.0 x 75.0 x 125.0 mm

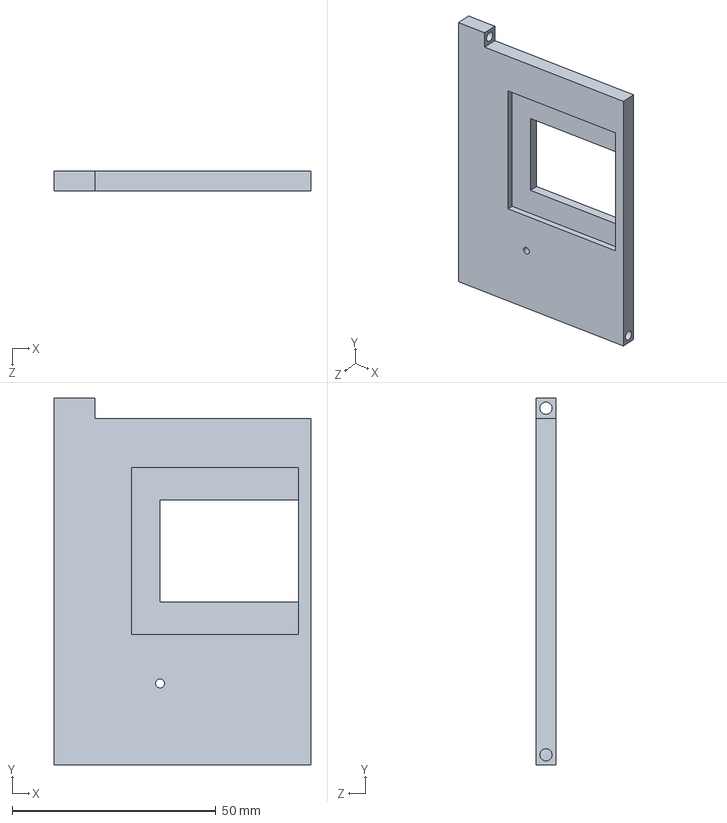
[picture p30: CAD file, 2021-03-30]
3D modeling/Multimuscles/SolidWorks/face oled 2.SLDPRT
63.0 x 90.0 x 5.00 mm

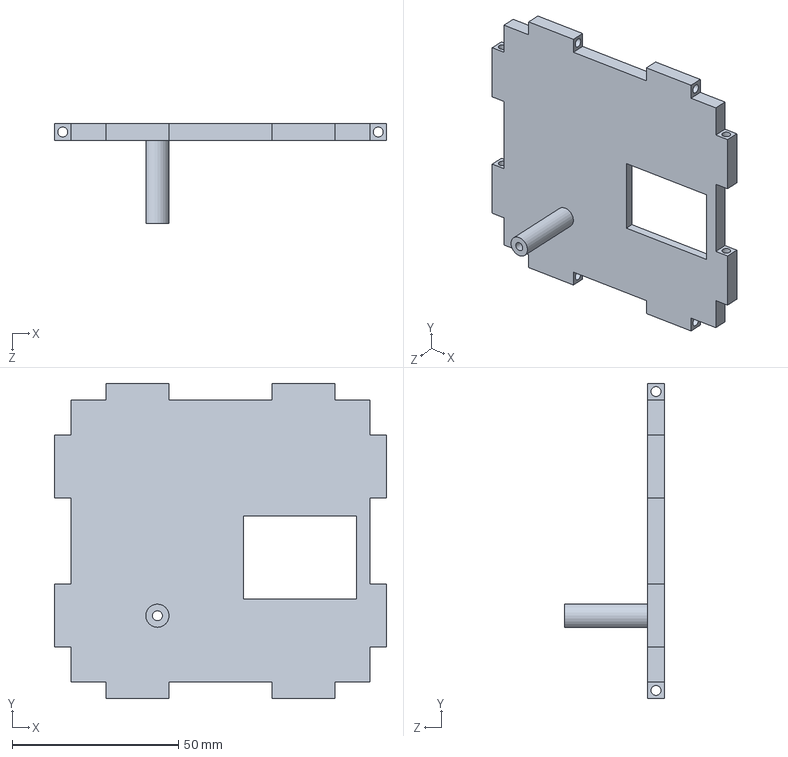
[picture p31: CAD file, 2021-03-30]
3D modeling/Monomuscle/SolidWorks/face oled.SLDPRT
100.0 x 95.0 x 30.0 mm

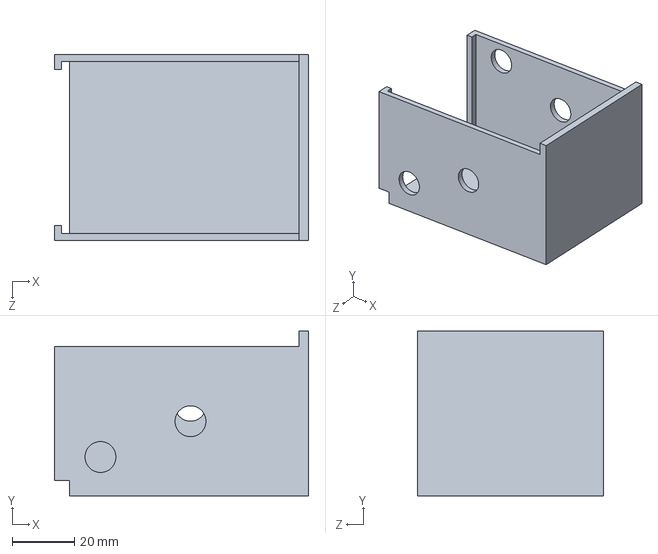
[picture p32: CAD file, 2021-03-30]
3D modeling/Multimuscles/SolidWorks/extension.SLDPRT
81.8 x 53.0 x 60.0 mm

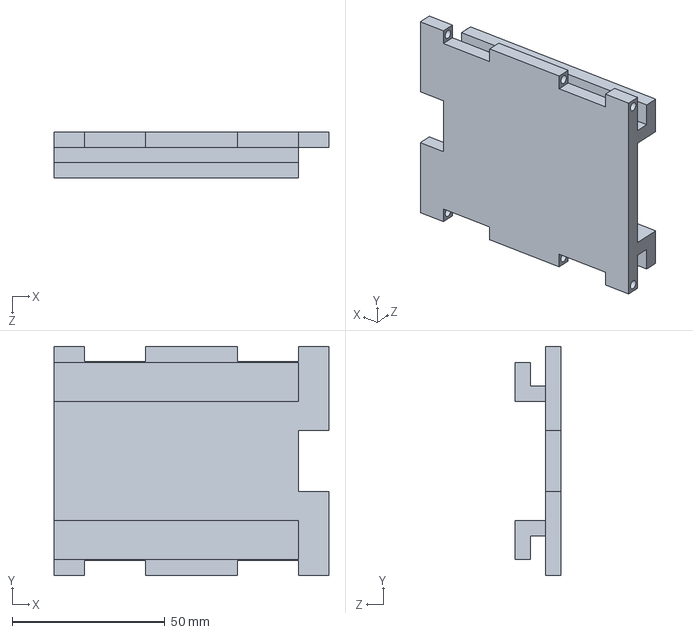
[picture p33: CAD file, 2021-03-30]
3D modeling/Monomuscle/SolidWorks/support porte pile.SLDPRT
90.0 x 75.0 x 15.0 mm

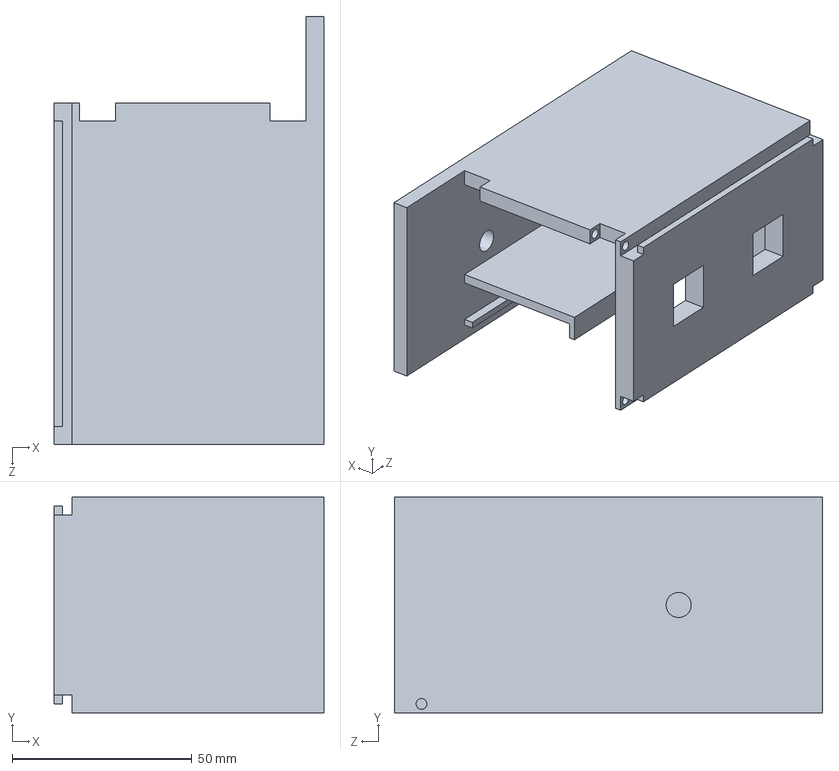
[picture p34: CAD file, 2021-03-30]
3D modeling/Multimuscles/SolidWorks/piece principale 2.SLDPRT
75.0 x 60.0 x 119.0 mm

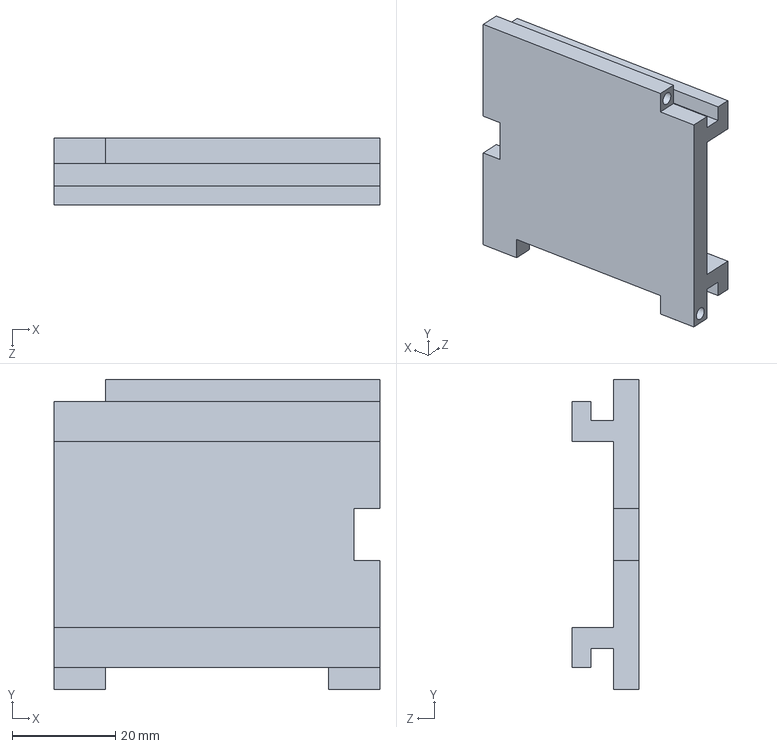
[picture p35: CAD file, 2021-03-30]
3D modeling/Multimuscles/SolidWorks/support porte pile 2.SLDPRT
63.0 x 60.0 x 13.0 mm

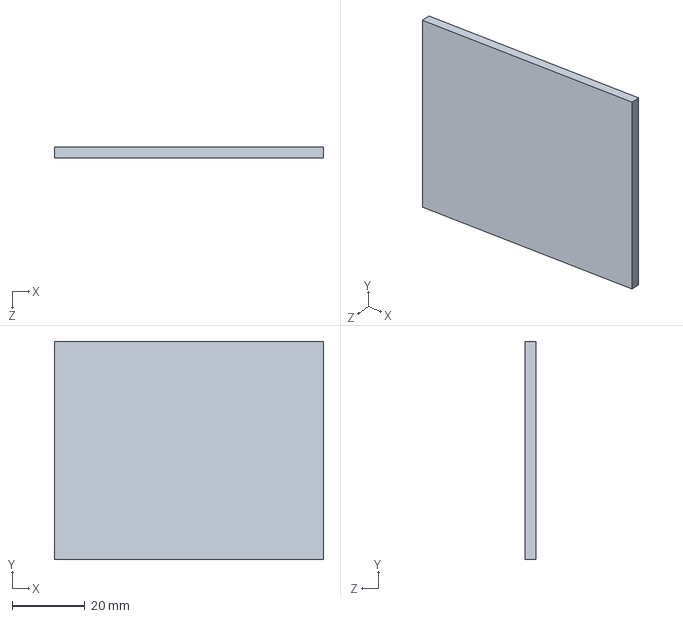
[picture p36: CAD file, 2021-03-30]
3D modeling/Multimuscles/SolidWorks/top_extension.SLDPRT
74.0 x 60.0 x 3.00 mm

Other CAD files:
3D modeling/Monomuscle/3D Printing/capuchon.STL
3D modeling/Monomuscle/3D Printing/face oled.STL
3D modeling/Monomuscle/3D Printing/piece principal.STL
3D modeling/Monomuscle/3D Printing/support porte pile.STL
3D modeling/Multimuscles/3D Printing/capuchon 2.STL
3D modeling/Multimuscles/3D Printing/extension.STL
3D modeling/Multimuscles/3D Printing/face oled 2.STL
3D modeling/Multimuscles/3D Printing/piece principale 2.STL
3D modeling/Multimuscles/3D Printing/support porte pile 2.STL
3D modeling/Multimuscles/3D Printing/top_extension.STL

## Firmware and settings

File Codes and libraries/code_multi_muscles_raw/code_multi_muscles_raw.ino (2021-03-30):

#include <Wire.h>
#include <U8g2lib.h> //Oled Library
#include <Filters.h>
#include <Filters/Butterworth.hpp>
#include "logo.h"

U8G2_SH1106_128X64_NONAME_F_HW_I2C u8g2(U8G2_R0,/*reset=*/U8X8_PIN_NONE);
//U8G2_SH1106_128X64_NONAME_F_HW_I2C u8g2(U8G2_R0,/*reset=*/U8G2_PIN_NONE);

const int max_muscles = 4;
float threshold[max_muscles];
int num_muscles = 1;

// constants won't change. They're used here to set pin numbers:
const int buttonPin = 19;     // the number of the pushbutton pin
const int buttonHigh = 18;
//Add as much pin_capteur and pin_transistor as you connect muscles on the case (max 8)
int pin_Capteur[] = {26,32};
int pin_Transistor[] = {25,33};
int array_values[128]; // tableau contenant les valeurs analogRead mappées pour l'affichage medecin


const int nEchantillons = 20;
float echantillon[nEchantillons]; // un tableau pour stocker les échantillons lus

const double f_s = 100; // Hz
// Cut-off frequency 
const double f_c = 2; // Hz
// Normalized cut-off frequency
const double f_n = 2 * f_c / f_s;
// Fourth-order Butterworth filter
auto filter1 = butter<4>(f_n);  // ici c'est un passe haut a priori a verifier sinon regarder comment utiliser passe bande (passe haut - passe bas le tout en butterworth ?)
   
// Cut-off frequency 
const double f_c2 = 40; // Hz
// Normalized cut-off frequency
const double f_n2 = 2 * f_c2 / f_s;
// Fourth-order Butterworth filter
auto filter2 = butter<4>(f_n2); 

void setup()
{
  u8g2.setFont(u8g2_font_6x13B_tf);
  pinMode(buttonPin, INPUT);
  pinMode(buttonHigh, OUTPUT);
  digitalWrite(buttonHigh, HIGH);
  u8g2.begin();
  drawLogo();
  delay(3000);
  Serial.begin(115200); //default baud rate for ESP32
  delay(100); // give time to bring up serial monitor
  u8g2.setFont(u8g2_font_6x13B_tf);
  
  DisplayOLED2("Let's Play To Heal!" ,0);
  DisplayOLED2("Distributed by",1);
  DisplayOLED2("Microsoft x ESILV",2);
  delay(3000);

  //set number of muscles to connect to the device.
  num_muscles = CountMuscles();
  
  //set the loop that iterates as many times as there are muscles to connect
  for (int m=0; m<num_muscles; m++){
    pinMode(pin_Transistor[m], OUTPUT);
    digitalWrite(pin_Transistor[m], LOW);

    DisplayOLED2("Muscle "+String(m+1),0);
    DisplayOLED2("Relax then",1);
    DisplayOLED2("press button",2);

    int clic = 0;
    float moyenne_setup = 0.0;
    float total_setup = InitSample(m);

    // To initialize array_values
    for (int i = 0; i<128; i++){
      total_setup = UpdateSample(m,total_setup);
      moyenne_setup = sqrt(total_setup / nEchantillons);
      if(moyenne_setup<20) moyenne_setup = 20; 
      array_values[i] = map(moyenne_setup,20,210,63,0);
      delay(1);
    }

    while(clic != 1){
      if(digitalRead(buttonPin)==HIGH) clic = clic +1;
    }

    DisplayOLED2("Stay decontracted",0);
    delay(3000);
    // We have the minimum mean value
    int moyenne_min = Mean(m);

    DisplayOLED2("Value Decontracted:",0);
    DisplayOLED2(String(moyenne_min),1);
    delay(3000);
    
    DisplayOLED2("Contract muscle "+String(m+1),0);
    DisplayOLED2("Keep contracting",1);
    DisplayOLED2("when pressing Button",2);
    
    while(clic != 2){
      if(digitalRead(buttonPin)==HIGH) clic = clic +1;
    }

    DisplayOLED2("Stay Contracted",0);
    delay(3000);
    // We have the contracted mean value
    int moyenne_max = Mean(m);
    DisplayOLED2("Value Contracted:",0);
    DisplayOLED2(String(moyenne_max),1);
    delay(3000);
    
    threshold[m] = moyenne_min + 0.3 * (moyenne_max - moyenne_min);
    DisplayOLED2("Threshold "+String(m+1)+":",0);
    DisplayOLED2(String(threshold[m]),1);
    delay(3000);
  }
}
  

void loop()
{
  for(int m=0; m<num_muscles; m++){
    SendSignal(m);
  }
  delay(10);
}

float Mean(int m)
{
  float mean_RMS=0.0;
  float total=0.0;
  float a=0.0;

  for(int ind=0; ind<nEchantillons; ind++){
    float valeur_capteur = analogRead(pin_Capteur[m]);
    a = filter1(valeur_capteur)-filter2(valeur_capteur);
    echantillon[ind] = a*a;
    total = total + echantillon[ind];
  }
  float mean = sqrt(total / nEchantillons);
  
  for (int i = 1; i < 250 ; i++){
    mean_RMS = sqrt(total / nEchantillons);
    if(mean_RMS - mean <50){     // a checker
        mean = mean*i/(i+1) + mean_RMS/(i+1);
    }
    else{
        i--; //On ne compte pas cette itération
    }
    DisplayCurve(m, i, total); 
    total = UpdateSample(m,total);
    delay(10);
  }
  return mean;
}

float InitSample(int m){
    float total = 0.0;
    float a = 0.0;
    for(int ind=0; ind<sizeof(echantillon); ind++){
        float valeur_capteur = analogRead(pin_Capteur[m]);
        a = filter1(valeur_capteur)-filter2(valeur_capteur);
        echantillon[ind] = a*a;
        total = total + echantillon[ind];
    }
    return total;
}

float UpdateSample(int m, float total){
  total = total - echantillon[0];
  int max_index = sizeof(echantillon)-1;
  for (int i = 0; i<max_index; i++){
    echantillon[i]= echantillon[i+1];
  }
  float valeur_capteur = analogRead(pin_Capteur[m]);
  float a = filter1(valeur_capteur)-filter2(valeur_capteur);
  echantillon[max_index] = a*a;
  
  total = total + echantillon[max_index];
  
  return total;
}

//Function that update the array of values registered from muscle m.
//This is mostly useful for the DisplayCurve function
void UpdateArray(int m, float total){
  // Fonction update tab
  for (int i = 0; i<127;i++){
    array_values[i]= array_values[i+1];
  }
  total = UpdateSample(m,total);
  float mean = sqrt(total / nEchantillons);
  if(mean<20)  mean = 20;
  //We map those values between 0 and 63 because this is the height of our OLED in pixels
  array_values[127] = map(mean,20,250,63,0);
}

//Function that displays on the OLED the curve of the contraction of muscle m.
void DisplayCurve(int m, int index, float total){
  UpdateArray(m, total);
  u8g2.clearBuffer();
  for (int i = 0; i<128;i++){
    int b = array_values[i];
    u8g2.drawPixel(i,b);
  }
  u8g2.setCursor(6, 30);
  u8g2.print(index);
  u8g2.sendBuffer();
}

//same function than previous one with the exception that to validate the number of muscles,
//user has to keep pressing the button for 2s instead of having to wait for the oled to display
//the confirmation message and click the button to confirm.
int CountMuscles(){
  //we need to know how many muscles the user is going to connect.
  //To do so, we can ask the user to click the button as many times as he wants muscles
  int muscles = 1;
  bool changed = true;
  bool memo_appuiLong = false;
  double memo_temps = 0;
  int appuiLimite = 2000;
  
  DisplayOLED2("Click to add muscle",0);
  DisplayOLED2(String(muscles)+" so far",1);
  DisplayOLED2("Press 2s to validate",2);
  
  while(changed){
    double temps = millis();
    if (digitalRead(buttonPin)==HIGH) { // si le bouton est à HIGH
        if (temps - memo_temps > appuiLimite ){
          changed = false;
        }
        memo_appuiLong = true;       
    }
    else {
      if(memo_appuiLong) {
        muscles = (muscles%max_muscles +1);
        DisplayOLED2("Click to add muscle",0);
        DisplayOLED2(String(muscles)+" so far",1);
        DisplayOLED2("Press 2s to validate",2);
        memo_appuiLong = false;
      }
      memo_temps=temps; // mémorise le temps quand on a appuyé sur le bouton
    }
  }
  DisplayOLED2(String(muscles)+" muscles to connect",0);
  delay(3000);
  return muscles;
}


//Function that sets the voltage of the pin transistor of muscle m to HIGH (=Contact) if the value read
//on pin capteur of muscle m is higher than the previously set threshold for muscle m
void SendSignal(int m){
  float total = InitSample(m);
  float moyenne = sqrt(total / nEchantillons);
  
  if(moyenne>threshold[m]){
    digitalWrite(pin_Transistor[m], HIGH);
    DisplayOLED2("CONTACT "+String(m+1),m);
  }
  else{
    digitalWrite(pin_Transistor[m], LOW);
    DisplayOLED2("RAS "+String(m+1),m);
  }
}

//Function to display elements on the OLED
//This function takes into parameters one string and one integer corresponding to the position of the String.
//If the position of the string is 0, then we have to clear the buffer first then display it.
//Otherwise we simply display the string without clearing the buffer.
//Thanks to this function, we don't deal with arrays anymore and the display works perfectly.
void DisplayOLED2(String s, int pos){
  if(pos==0){u8g2.clearBuffer();}
  u8g2.setCursor(6, 10+20*pos);
  u8g2.print(s);
  u8g2.sendBuffer();
}

void drawLogo() {
 u8g2.firstPage();
 do {
   u8g2.drawXBMP(0, 0, logo_width, logo_height, logo);
 } while ( u8g2.nextPage() );
}
